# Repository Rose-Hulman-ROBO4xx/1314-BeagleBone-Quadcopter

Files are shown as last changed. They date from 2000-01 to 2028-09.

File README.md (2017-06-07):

Snoopy Copter
==========================
The quadcopter project got a rename recently. Named for the popular Peanuts character Snoopy, who always dreamed of flight, our flying Beaglebone will hopefully aid Snoopy in his quest to defeat the Red Baron!

Create an inexpensive open-source project for a BeagleBone cape quadcopter. As of the beginning of April, 2014, we have flight! Some videos of the initial flight testing are located [here](https://www.dropbox.com/sh/0pfk43b3zq14rjh/xk6Kl6lccb#/). Since then, the quadcopter has gotten easier to fly and more stable.

## Pictures ##
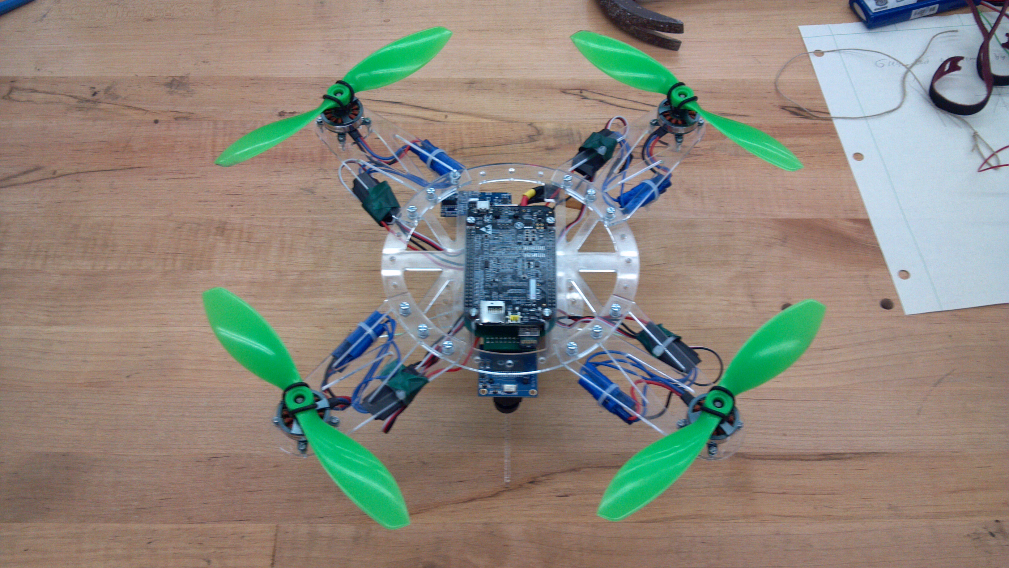
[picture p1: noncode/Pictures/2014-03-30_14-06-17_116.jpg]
View 1


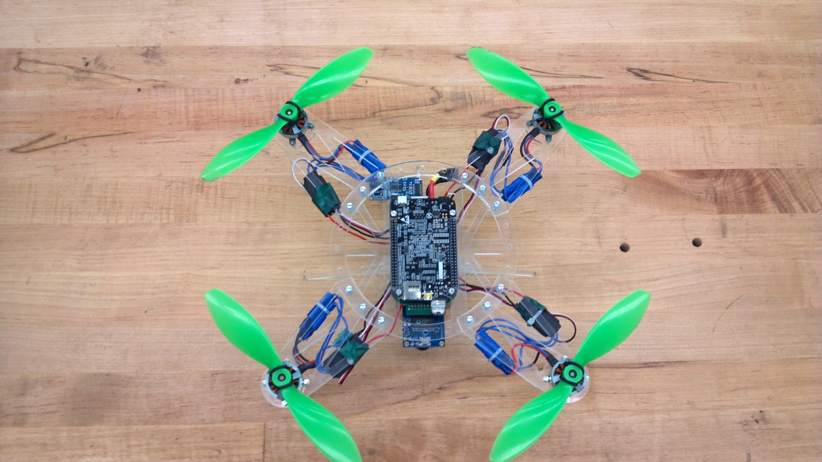
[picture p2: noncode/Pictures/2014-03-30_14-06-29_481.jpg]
View 2


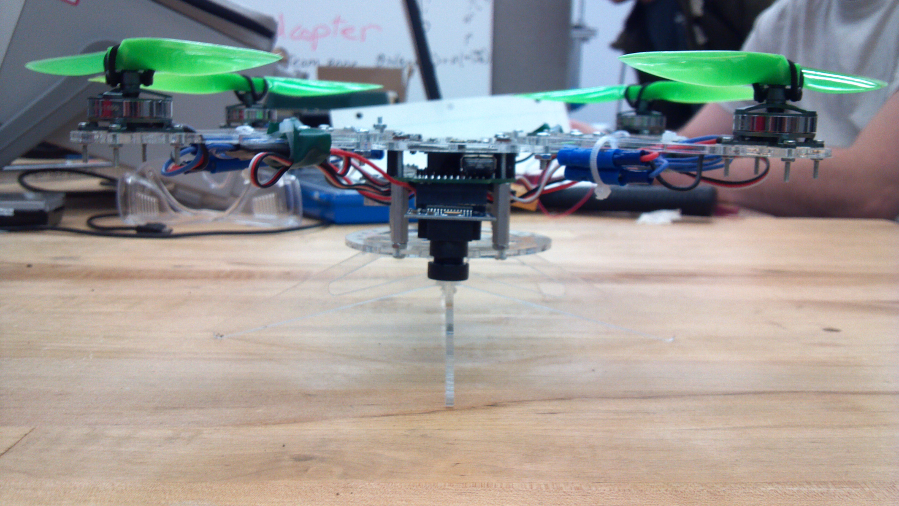
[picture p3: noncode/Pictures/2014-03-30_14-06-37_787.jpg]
View 3


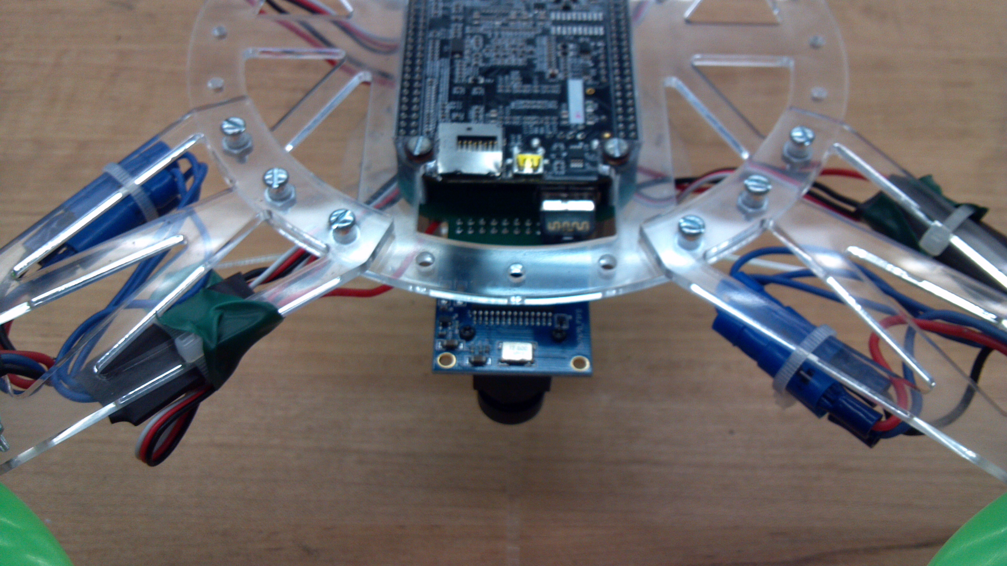
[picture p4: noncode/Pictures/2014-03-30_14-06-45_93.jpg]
View 4


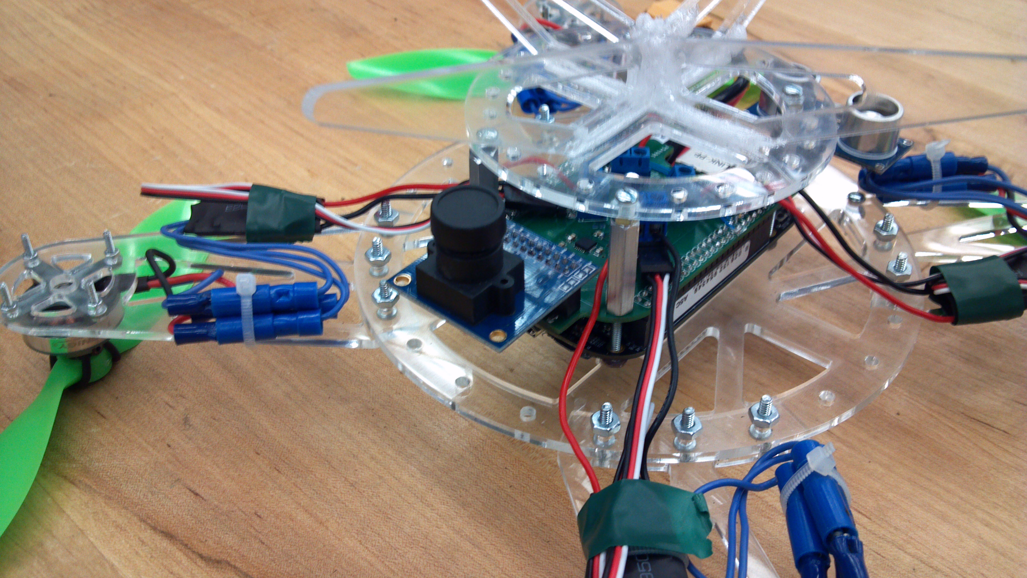
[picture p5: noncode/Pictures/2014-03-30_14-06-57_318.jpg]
View 5


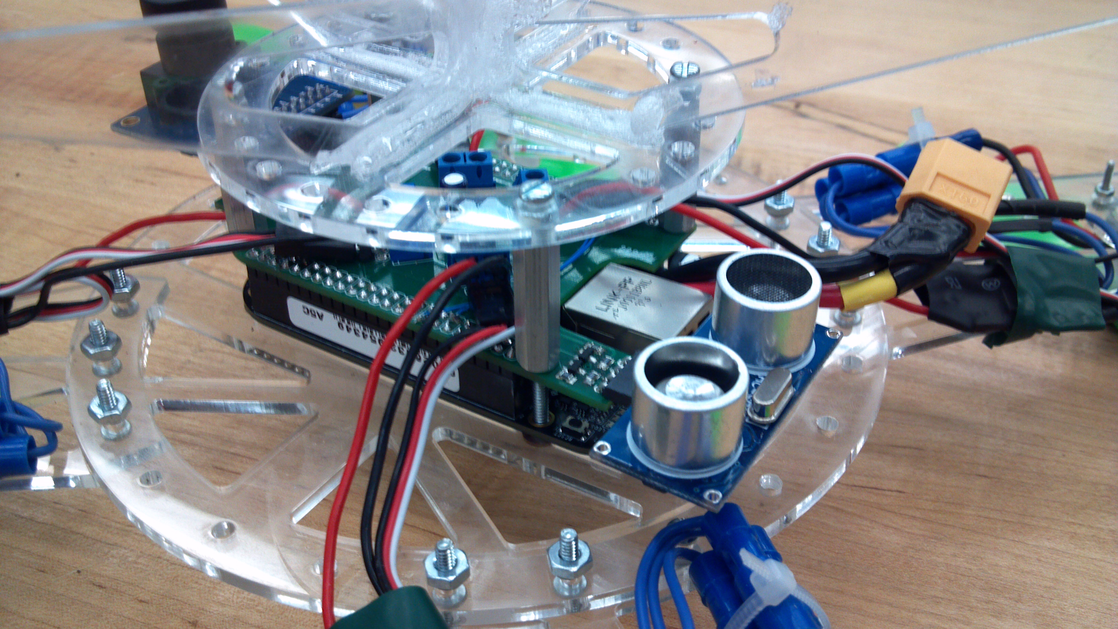
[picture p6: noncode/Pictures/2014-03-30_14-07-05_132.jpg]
View 6


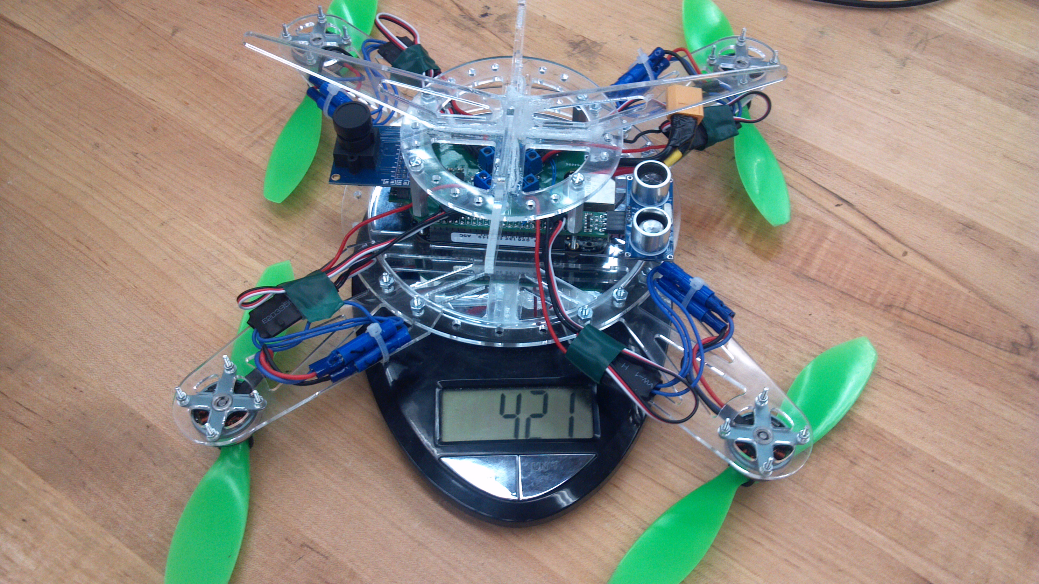
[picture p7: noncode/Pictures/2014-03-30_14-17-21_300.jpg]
View 7


421 grams!

## License ##
All software and hardware designs (frame, circuit board, etc.) here are under Creative Commons Non-Commercial Share-Alike V3.0 License, located [here](http://creativecommons.org/licenses/by-nc-sa/3.0/us/legalcode).

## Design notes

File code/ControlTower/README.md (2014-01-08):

Quadcopter Server README
========================

Necessary Hardware
------------------
1. BeagleBone Black running the latest image (9/4/2013 or later)
2. MPU 6050 six axis accelerometer and gyro
3. UWN 100 or UWN 200 USB WiFi Dongle
4. Wireless access point

Additional components such as wires and a power source may be helpful.

Necessary Software
------------------
1. Node.js
2. Various node packaged modules (I2C and MPU6050)
3. JQuery and flot
4. Source code files

All files except the installation of Node are available on this repo.

Installation
------------
1. Install Node.js
2. Install NPM
3. Install I2C and MPU6050 from NPM
4. Download all source to the correct directory

Useage
------
1. Connect the BBB to your wireless access point
2. Connect the host to the same network
3. Navigate to the proper IP address of the BBB, port 1337
4. Enjoy watching your data in real time

### Credits ###
Mike McDonald and Matt Skorina
Rose-Hulman ECE 497 Fall 2013
More detailed instructions for this project are available on the eLinux.org Wiki, located [here](http://elinux.org/ECE497_Project_Quadcopter_Server).

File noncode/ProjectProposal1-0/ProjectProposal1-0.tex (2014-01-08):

\documentclass[a4paper,10pt]{scrartcl}
\usepackage[utf8]{inputenc}
\usepackage{graphicx}

%opening
\title{Quadcopter Project Proposal}
\subtitle{ROBO 410 Dr. Mark Yoder}
\author{Team Bone and Team Sky: \\
	{\normalsize Bryce Filho (filhobc@rose-hulman.edu) }\\
	{\normalsize Chris Hopwood (hopwoocp@rose-hulman.edu) }\\
	{\normalsize Michael McDonald (mcdonamp@rose-hulman.edu) }\\
	{\normalsize Shawn Mitchell (mitchesm@rose-hulman.edu) }\\
	{\normalsize Daniel Nam (namdw@rose-hulman.edu) }\\
	{\normalsize Ryan Oliver (oliverr@rose-hulman.edu) }\\
	{\normalsize Justin Stone (stonejp@rose-hulman.edu) }\\
	{\normalsize Elias White (whiteer@rose-hulman.edu) }\\
	}

\begin{document}

\maketitle

\newpage

\tableofcontents

\begin{table}[b]
\centering
\begin{tabular}{| l | l | p{7.5cm} |}
\hline
\textbf{Revision} & \textbf{Date} & \textbf{Comments}\\
\hline
1.0 & 9/25/2013 & Initial Copy \\
\hline
\end{tabular}
\end{table}

\newpage

\section{Executive Summary}
\noindent The goal of this project is to create a plug-and-play quadcopter
add-on, or cape, solution for the BeagleBone Black.  With the recent explosion
of quadcopters among hobbyists and researchers, a platform that is affordable,
powerful without being overwhelming, and expandable fills a unique niche in the
current market. With the release of TI's BeagleBone Black, a very capable yet
affordable embedded processor, all three of these goals are attainable. The
successful completion of this project would result in a mechanical design for
the quadcopter frame, a BeagleBone Cape that houses sensors and motor
controllers, integrated flight control software for in-flight stabilization, and
the ability to communicate with a control base. We will be leveraging both our
resources at TI as well as the open source community throughout the course of
our project, and plan on open sourcing the mechanical designs, PCB schematic and
layout files, and source code.

\newpage
\section{Walkthrough}
\noindent The client contact at TI (currently Jason Kridner, the main software
developer on the Beagle Board/Bone platform) wants a quadcopter expansion
board/cape for the BeagleBone Black that is out of the box ready to fly or
almost ready to fly quadcopter, yet can still be expanded upon by the
hobbyist community and the users themselves. \\

\noindent The QuadCape and BeagleBone Black can be ordered on the client’s
website or through selected third party distributors. Upon delivery, the
customer will open the packaging and assemble the kit by attaching the
BeagleBone Black to the QuadCape, and attaching motors, propellers, and a
battery (all of which are either shipped with the kit or provided by the
user). \\

\noindent After enabling flight mode by pressing the on switch on the cape, an
LED will light indicating that the quadcopter has power and it's sensors have
been initialized. The quadcopter will then begin to fly; stably and slowly
raising altitude relative to its initial altitude. The user will then be able to
control the quadcopter via wireless communication: either a laptop or a mobile
device (phone or tablet). \\

\noindent To add functionality to the quadcopter, the customer can add software
through the continually evolving open source community that already exists
around the BeagleBone. The customer can also add hardware to the quadcopter
through any of the multiple ports of the BeagleBone Black by adding capes or
modifying the QuadCape board and building one themselves. If the user happens to
break anything, parts for the QuadCape or the quadcopter frame will be available
for purchase, and the design files will be published so users could build their
own replacements. Through this open source community the quadcopter will have
greater opportunity to be any type of project the client chooses, and will boost
the reputation of TI and the BeagleBone.

\newpage
\section{Domain Model}
\begin{figure}[h]
 \centering
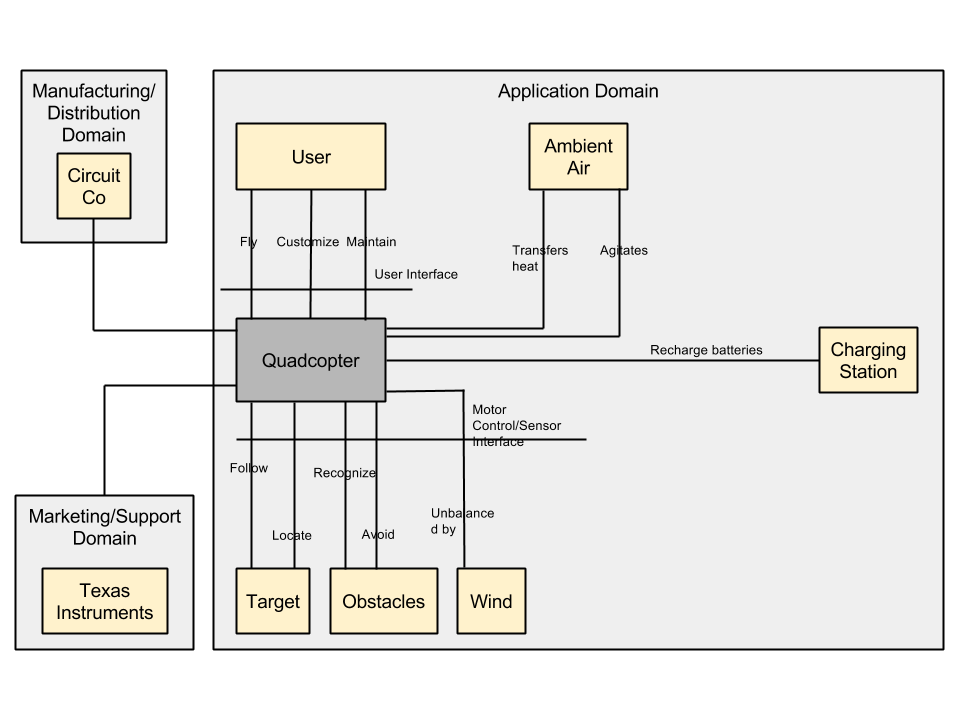
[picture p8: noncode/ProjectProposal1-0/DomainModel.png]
 
 % Domain Model.png: 960x720 pixel, 72dpi, 33.87x25.40 cm, bb=0 0 960 720
 \caption{Domain Model}
\end{figure}

\newpage
\section{Stakeholder Model}
\begin{center}
\begin{tabular}{| l | p{7.5cm} |}
\hline
\textbf{Stakeholder} & \textbf{Features}\\
\hline
Dr. Mark Yoder and Rose-Hulman & \emph{Documentation}: should be reproducible,
allow for easy future use and modification\newline
\emph{Manufacturing Cost and Time}: should be a completed product within spec
and budget, maintain/improve relationship with Texas Instruments\newline
\emph{Safety}: should be safe to build/test, as well as operate in the
future\newline
\emph{Operation Costs}: should not require special equipment or additional
overhead to use in the future\\
\hline
Jason Kridner and Texas Instruments & \emph{Customization}: should allow for
user customization, act as a marketing tool to sell additional TI products
\emph{Documentation}: should be reproducible, portable to other TI
controllers/launchpads\newline
\emph{Manufacturing Cost and Time}: should be cheap and quick to manufacture in
order to sell at a reasonable price and be more appealing than building a
quadcopter from scratch\\
\hline
CircuitCo & \emph{Customization}: should allow for expansion, without
interfering with original design and manufacturing process, may provide other
manufacturing/sales opportunities\newline
\emph{Durability}: should be well-designed and not require replacements under
warranty for normal usage\newline
\emph{Manufacturing Cost and Time}: should be efficient to manufacture, minimal
waste\newline
\emph{Maintenance}: should not require extensive hardware support\newline
\emph{Packaging}: should fit into a standard package and minimize inventory
space, be easy to ship individually and in bulk\newline
\emph{Regulatory Compliance}: should be designed to meet regulations and not
interfere with or delay the manufacturing process\\
\hline
\end{tabular}
\end{center}

\newpage
\begin{center}
\begin{tabular}{| l | p{7.5cm} |}
\hline
Hobbyist Community & \emph{Customization}: should act as a platform for design
and experimentation, should be easy to incorporate other projects, remain
open source\newline
\emph{Durability}: should be able to withstand testing and experimentation,
avoid severely damaging components\newline
\emph{Maintenance}: should be supported into its life cycle, offer replacement
parts or firmware updates\newline
\emph{Safety}: should not be a hazard to the operator or bystanders, or be
unnecessarily dangerous to modify\newline
\emph{Reliability}: both hardware and software should be robust, as countless
hours and funds may be invested into projects revolving around the
product\newline
\emph{Ease of Use}: should be easy to operate and interface with, more appealing
than building a quadcopter from scratch\newline
\emph{Operation Costs}: should not require special equipment or additional
overhead to use in the future\\
\hline
Educational Community & \emph{Customization}: should act as a platform for
design and experimentation, should be easy to incorporate other projects, remain
open source\newline
\emph{Durability}: should be able to withstand testing and experimentation,
avoid severely damaging components, resistant to student misuse
\emph{Maintenance}: should be supported into its life cycle, offer replacement
parts or firmware updates, should require minimal technical knowledge to keep
product operational\newline
\emph{Safety}: should not be a hazard to the operator or bystanders, or be
unnecessarily dangerous to modify, should be safe to use around
children/students\newline
\emph{Reliability}: both hardware and software should be robust, as countless
hours and funds may be invested into projects revolving around the
product\newline
\emph{Ease of Use}: should be easy to operate and interface with, more appealing
than building a quadcopter from scratch, should require minimal technical
knowledge to operate the completed product\newline
\emph{Operation Costs}: should not require special equipment or additional
overhead to use in the future\\
\hline
Regional Community & \emph{Environment Friendly}: should not harm the
environment through operation, provide options for disposal or recycling\newline
\emph{Safety}: should be safe to operate within a community, on a larger scale\\
\hline
\end{tabular}
\end{center}

\newpage
\section{State Model}
\begin{figure}[h]
 \centering
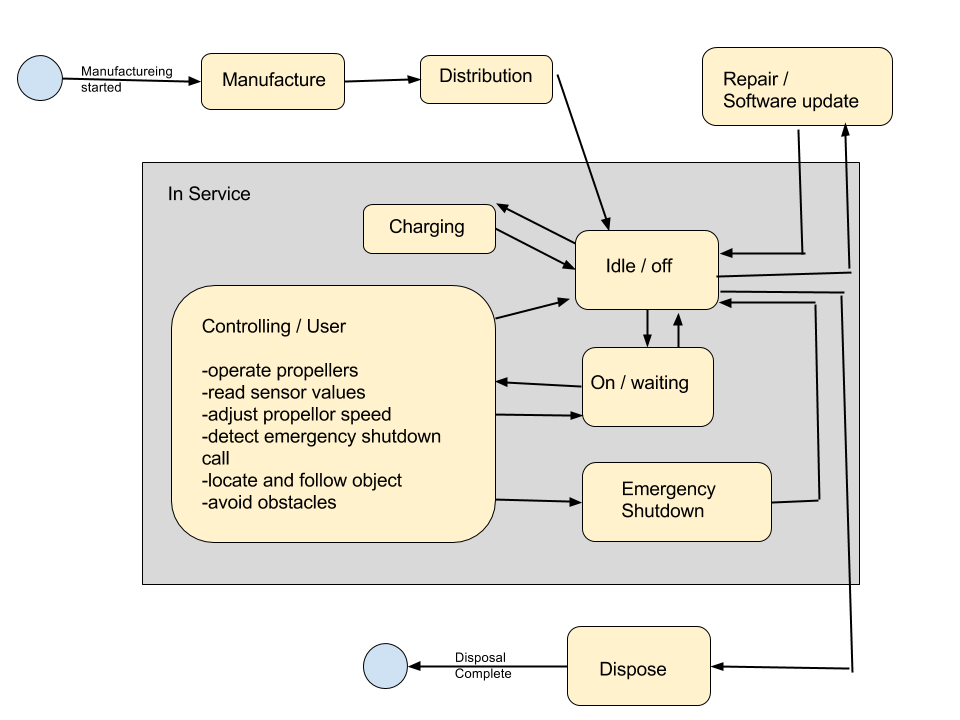
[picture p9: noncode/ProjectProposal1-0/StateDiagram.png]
 
 % State Diagram.png: 960x720 pixel, 72dpi, 33.87x25.40 cm, bb=0 0 960 720
 \caption{State Diagram}
\end{figure}

\newpage
\section{Logical Architecture}
\begin{figure}[h]
 \centering
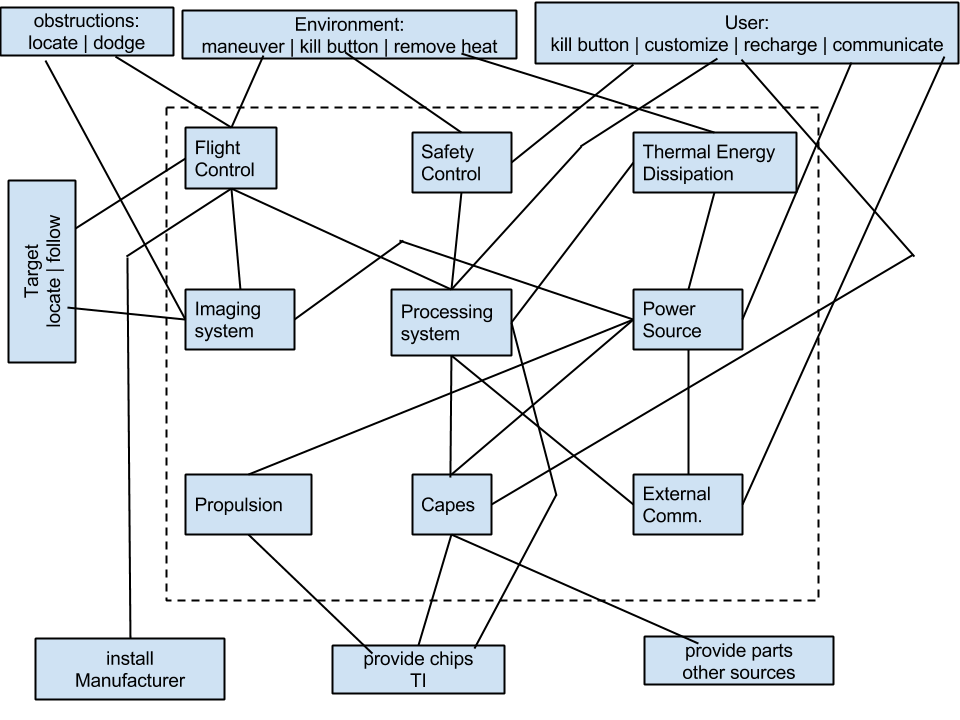
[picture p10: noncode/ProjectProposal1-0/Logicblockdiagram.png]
 
 % Logic block diagram.png: 960x720 pixel, 72dpi, 33.87x25.40 cm, bb=0 0 960 720
 \caption{Logical Architecture}
\end{figure}

\end{document}

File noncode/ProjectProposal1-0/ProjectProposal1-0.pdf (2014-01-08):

# Quadcopter Project Proposal

ROBO 410 Dr. Mark Yoder

## Team Bone and Team Sky:

Bryce Filho (filhobc@rose-hulman.edu)

Chris Hopwood (hopwoocp@rose-hulman.edu)

Michael McDonald (mcdonamp@rose-hulman.edu)

Shawn Mitchell (mitchesm@rose-hulman.edu)

Daniel Nam (namdw@rose-hulman.edu)

Ryan Oliver (oliverr@rose-hulman.edu)

Justin Stone (stonejp@rose-hulman.edu)

Elias White (whiteer@rose-hulman.edu)

## September 24, 2013

1

## Contents

1 Executive Summary | 3
2 Walkthrough | 4
3 Domain Model | 5
4 Stakeholder Model | 6
5 State Model | 9
6 Logical Architecture | 10
Revision | Date | Comments
1.0 | 9/25/2013 | Initial Copy

2

## 1 Executive Summary

The goal of this project is to create a plug-and-play quadcopter add-on, or cape, solution for the BeagleBone Black. With the recent explosion of quadcopters among hobbyists and researchers, a platform that is affordable, powerful without being overwhelming, and expandable fills a unique niche in the current market. With the release of TI’s BeagleBone Black, a very capable yet affordable embedded processor, all three of these goals are attainable. The successful completion of this project would result in a mechanical design for the quadcopter frame, a BeagleBone Cape that houses sensors and motor controllers, integrated flight control software for in-flight stabilization, and the ability to communicate with a control base. We will be leveraging both our resources at TI as well as the open source community throughout the course of our project, and plan on open sourcing the mechanical designs, PCB schematic and layout files, and source code.

3

## 2 Walkthrough

The client contact at TI (currently Jason Kridner, the main software developer on the Beagle Board/Bone platform) wants a quadcopter expansion board/cape for the BeagleBone Black that is out of the box ready to fly or almost ready to fly quadcopter, yet can still be expanded upon by the hobbyist community and the users themselves.

The QuadCape and BeagleBone Black can be ordered on the client’s website or through selected third party distributors. Upon delivery, the customer will open the packaging and assemble the kit by attaching the BeagleBone Black to the QuadCape, and attaching motors, propellers, and a battery (all of which are either shipped with the kit or provided by the user).

After enabling flight mode by pressing the on switch on the cape, an LED will light indicating that the quadcopter has power and it’s sensors have been initialized. The quadcopter will then begin to fly; stably and slowly raising altitude relative to its initial altitude. The user will then be able to control the quadcopter via wireless communication: either a laptop or a mobile device (phone or tablet).

To add functionality to the quadcopter, the customer can add software through the continually evolving open source community that already exists around the Beagle-Bone. The customer can also add hardware to the quadcopter through any of the multiple ports of the BeagleBone Black by adding capes or modifying the QuadCape board and building one themselves. If the user happens to break anything, parts for the QuadCape or the quadcopter frame will be available for purchase, and the design files will be published so users could build their own replacements. Through this open source community the quadcopter will have greater opportunity to be any type of project the client chooses, and will boost the reputation of TI and the BeagleBone.

4

## 3 Domain Model

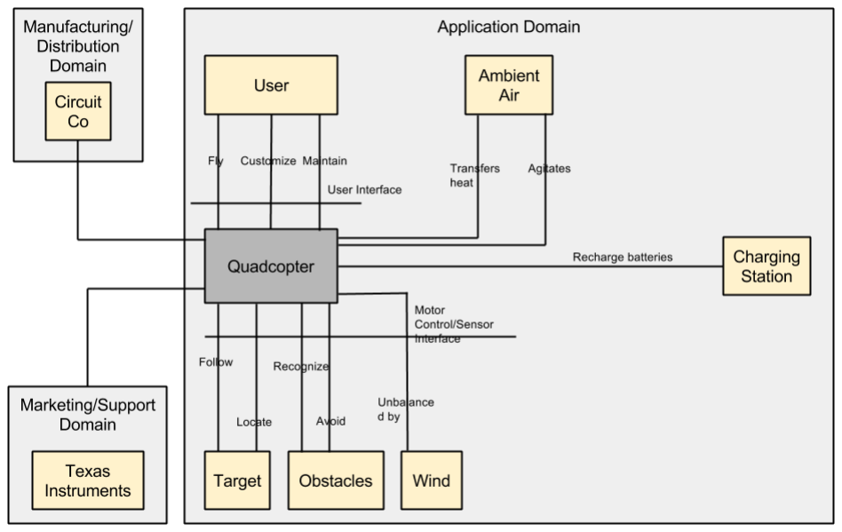
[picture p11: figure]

Figure 1: Domain Model

5

## 4 Stakeholder Model

Stakeholder | Features
Dr. Mark Yoder and Rose-Hulman | Documentation: should be reproducible, allow for easy future use and modification Manufacturing Cost and Time: should be a com-pleted product within spec and budget, main-tain/improve relationship with Texas Instru-ments Safety: should be safe to build/test, as well as operate in the future Operation Costs: should not require special equipment or additional overhead to use in the future
Jason Kridner and Texas Instruments | Customization: should allow for user customiza-tion, act as a marketing tool to sell ad-ditional TI products Documentation: should be reproducible, portable to other TI con-trollers/launchpads Manufacturing Cost and Time: should be cheap and quick to manufacture in order to sell at a rea-sonable price and be more appealing than build-ing a quadcopter from scratch
CircuitCo | Customization: should allow for expansion, with- out interfering with original design and manufac- turing process, may provide other manufactur- ing/sales opportunities Durability: should be well-designed and not re- quire replacements under warranty for normal us- age Manufacturing Cost and Time: should be effi- cient to manufacture, minimal waste Maintenance: should not require extensive hard- ware support Packaging: should fit into a standard package and minimize inventory space, be easy to ship individ- ually and in bulk Regulatory Compliance: should be designed to meet regulations and not interfere with or delay the manufacturing process

6

Hobbyist Community Customization: should act as a platform for design and experimentation, should be easy to incorporate other projects, remain open source Durability: should be able to withstand testing and experimentation, avoid severely damaging components
Maintenance: should be supported into its life cycle, offer replacement parts or firmware updates Safety: should not be a hazard to the operator or bystanders, or be unnecessarily dangerous to modify
Reliability: both hardware and software should be robust, as countless hours and funds may be invested into projects revolving around the product
Ease of Use: should be easy to operate and interface with, more appealing than building a quadcopter from scratch
Operation Costs: should not require special equipment or additional overhead to use in the future
Educational Community Customization: should act as a platform for design and experimentation, should be easy to incorporate other projects, remain open source Durability: should be able to withstand testing and experimentation, avoid severely damaging components, resistant to student misuse Maintenance: should be supported into its life cycle, offer replacement parts or firmware updates, should require minimal technical knowledge to keep product operational
Safety: should not be a hazard to the operator or bystanders, or be unnecessarily dangerous to modify, should be safe to use around children/students
Reliability: both hardware and software should be robust, as countless hours and funds may be invested into projects revolving around the product
Ease of Use: should be easy to operate and interface with, more appealing than building a quadcopter from scratch, should require minimal technical knowledge to operate the completed product Operation Costs: should not require special equipment or additional overhead to use in the future
Regional Community Environment Friendly: should not harm the environment through operation, provide options for disposal or recycling
Safety: should be safe to operate within a community, on a larger scale

7

## 5 State Model

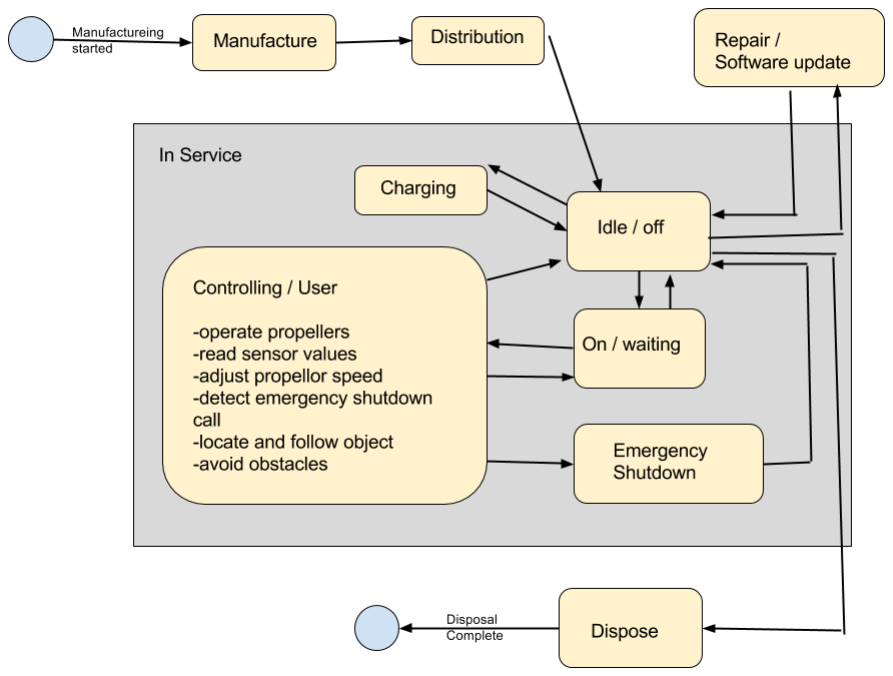
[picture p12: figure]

Figure 2: State Diagram

8

## 6 Logical Architecture

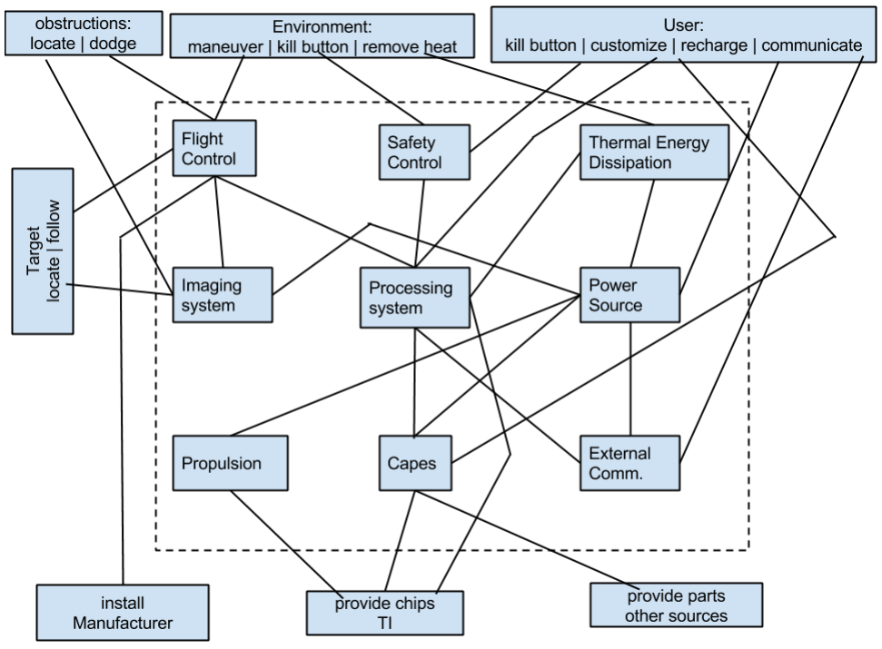
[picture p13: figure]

Figure 3: Logical Architecture

9

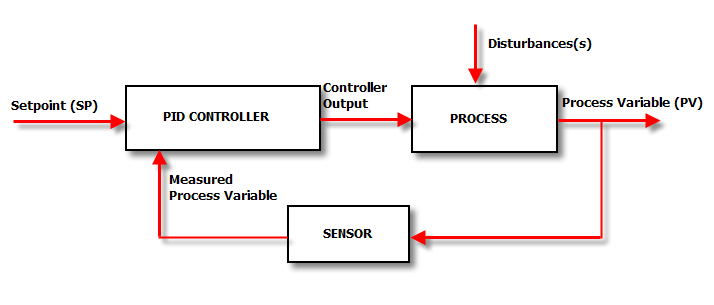
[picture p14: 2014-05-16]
noncode/Pictures/PWM Process Overview.png

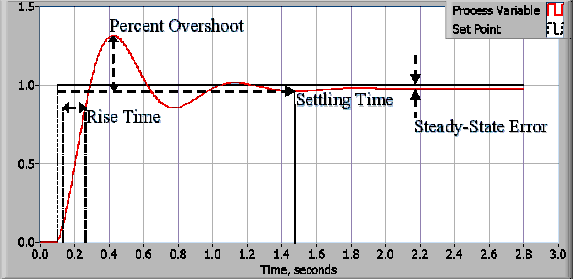
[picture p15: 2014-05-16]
noncode/Pictures/Example Output.png

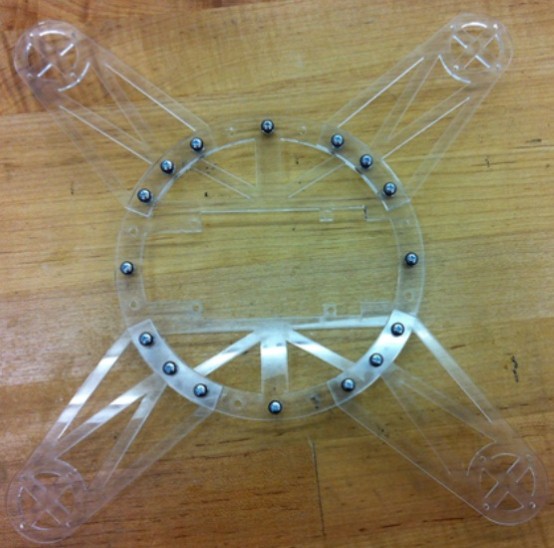
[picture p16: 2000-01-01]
code/ControlTower/images/Frame.jpg

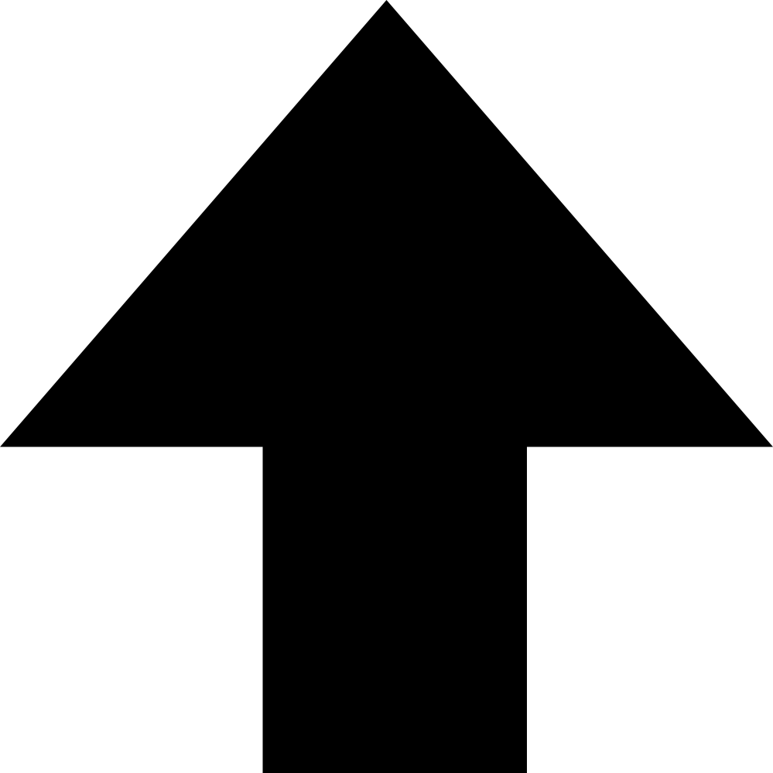
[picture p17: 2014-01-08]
code/ControlTower/Images/up_arrow-999px.png

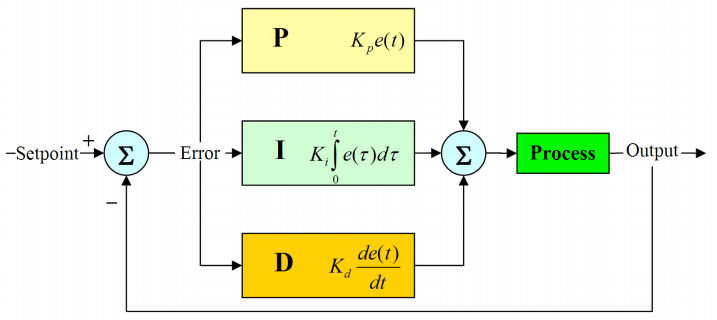
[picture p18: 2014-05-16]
noncode/Pictures/PID Control.png

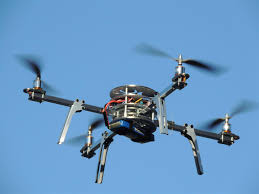
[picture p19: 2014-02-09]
code/ControlTower/images/quadcopter.jpg

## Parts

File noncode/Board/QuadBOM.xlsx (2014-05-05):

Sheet: Board
Qty | Value | Device | Package | Parts | Description | MF | MPN | Purchase Link | Individual | 1k Volume Cost | Line Total (Individual) | Line Total (Volume)
4 | 0.1uF 6.3V | C-USC0805 | C0805 | C1, C2, C6, C7 | CAPACITOR, American symbol | Kemet | C0805C104K9RACTU | http://www.digikey.com/product-detail/en/C0805C104K9RACTU/399-9155-1-ND/3522673 | 0.12 | 0.02228 | 0.48 | 0.08912
1 | 2.2nF 50V | C-USC0805 | C0805 | C3 | CAPACITOR, American symbol | Kemet | C0805C222K5RACTU | http://www.digikey.com/product-detail/en/C0805C222K5RACTU/399-1151-1-ND/411426 | 0.1 | 0.0102 | 0.1 | 0.0102
3 | 10nF 16V | C-USC0805 | C0805 | C4, C9, C11 | CAPACITOR, American symbol | Kemet | C0805C103K4RACTU | http://www.digikey.com/product-detail/en/C0805C103K4RACTU/399-7995-1-ND/3471718 | 0.24 | 0.05875 | 0.72 | 0.17625
1 | 10uF 25V |  | CPOL-RADIAL-10UF-25V | C5 | CAP-08440 | CDE | SK100M025ST | http://www.digikey.com/product-detail/en/SK100M025ST/338-1697-ND/1627382 | 0.21 | 0.078 | 0.21 | 0.078
2 | 1uF 16V | C-USC0805 | C0805 | C8, C10 | CAPACITOR, American symbol | Kemet | C0805C105K4RACTU | http://www.digikey.com/product-detail/en/C0805C105K4RACTU/399-1284-1-ND/416060 | 0.12 | 0.222 | 0.24 | 0.444
1 | M02PTH | M02PTH | 1X02 | JP1 | Standard 2-pin 0.1 header | Samtec | TSW-102-25-G-S-RA |  | 0.02906666667 | 0.01453506667 | 0.02906666667 | 0.01453506667
1 | M04PTH | M02PTH RA | 1x04 | JP10 | Standard 4-pin 0.1 header | Samtec | SSQ-104-02-G-S-RA |  | 1.11 | 0.55418 | 1.11 | 0.55418
1 | M211PTH | M211PTH | 2x11 | JP11 | Standard 2x11-pin 0.1 header | Samtec | SSQ-111-21-G-D |  | 2.58 | 1.2896 | 2.58 | 1.2896
4 | M03PTH | M03PTH RA | 1X03 | JP2, JP3, JP4, JP5 | Standard 3-pin 0.1 header | Samtec | TSW-103-25-G-S-RA |  | 0.0436 | 0.0218026 | 0.1744 | 0.0872104
4 | M025MM | M025MM | SCREWTERMINAL-5MM-2 | JP6, JP7, JP8, JP9 | 2-pin 5mm screw terminal | OST | OSTTC020162 | http://www.digikey.com/product-detail/en/OSTTC020162/ED2600-ND/614549 | 0.41 | 0.1925 | 1.64 | 0.77
1 | FB | INDUCTOR0805 | L0805 | L1 | Inductors | Laird | HZ0805E601R-10 | http://www.digikey.com/product-detail/en/HZ0805E601R-10/240-2399-1-ND/806759 | 0.1 | 0.02195 | 0.1 | 0.02195
1 | GREEN | LEDCHIP-LED0805 | CHIP-LED0805 | LED1 | LED GREEN | OSRAM Opto Semi | LG R971-KN-1 | http://www.digikey.com/product-detail/en/LG%20R971-KN-1/475-1410-1-ND/1802598 | 0.08 | 0.0437 | 0.08 | 0.0437
2 |  | BSS 138 | SOT23 | Q1, Q2 | N-Channel Mosfet | Fairchild | BSS 138 | http://www.digikey.com/product-detail/en/BSS138/BSS138CT-ND/244294 | 0.22 | 0.03998 | 0.44 | 0.07996
6 | 0 | R-US_M0805 | M0805 | R1, R5, R9, R10, R11, R12 | RESISTOR, American symbol | Stackpole | RMCF0805ZT0R00 | http://www.digikey.com/product-detail/en/RMCF0805ZT0R00/RMCF0805ZT0R00CT-ND/1942606 | 0.03 | 0.0032 | 0.18 | 0.0192
1 | 150 | R-US_M0805 | M0805 | R17 | RESISTOR, American symbol | Stackpole | RMCF0805JT150R | http://www.digikey.com/product-detail/en/RMCF0805JT150R/RMCF0805JT150RCT-ND/1942541 | 0.03 | 0.0032 | 0.03 | 0.0032
8 | 10000 | R-US_M0805 | M0805 | R2, R3, R4, R6, R13, R14, R15, R16 | RESISTOR, American symbol | Stackpole | RMCF0805FT10K0 | http://www.digikey.com/product-detail/en/RMCF0805FT10K0/RMCF0805FT10K0CT-ND/1942435 | 0.04 | 0.00448 | 0.32 | 0.03584
2 | 1000 | R-US_M0805 | M0805 | R7, R8 | RESISTOR, American symbol | Stackpole | RMCF0805JT1K00 | http://www.digikey.com/product-detail/en/RMCF0805JT1K00/RMCF0805JT1K00CT-ND/1942557 | 0.03 | 0.0032 | 0.06 | 0.0064
1 | BMP180 | BMP180 | BMP180 | U1 | BOSCH BMP180 DIGITAL BAROMETRIC PRESSURE SENSOR | Bosch Sensortec | BMP 180 | http://www.mouser.com/ProductDetail/Bosch-Sensortec/BMP180/?qs=sGAEpiMZZMsrChSOYEGTCcbpL13VfRyojs5HQb1tBiU%3d | 3.71 | 2.24 | 3.71 | 2.24
1 | MPU9150 | MPU-9150QFN-24-NP | QFN-24-NP | U2 | 9DOF (3mag, 3accel, 3rotat). I2C interface. | Invensense | MPU 9150 | http://www.digikey.com/product-detail/en/MPU-9150/1428-1009-1-ND/4038014 | 14.53 | 8.3 | 14.53 | 8.3
1 | GPS | GPS_FGPMMOPA6H | FGPMMOPA6H | U3 | GPS Module - MTK MT3339 Chipset, -165dBm sensitivity, 22 channels, 10Hz, auto-select external antenna options | GlobalTop Technology | FGPMMOPA6H | http://www.adafruit.com/products/790#Description | 29.95 | 15 | 29.95 | 15
1 | MAX1704X | MAX1704X | TDFN-8 | U4 | MAX17043/MAX17044: Battery Fuel Guage (43 is 1cell, 44 is 2cell) | Maxim Semiconductor | MAX 17044 |  | 2.15 | 1.22 | 2.15 | 1.22
1 | OMV-CAMERA | OMV-CAMERA | OMV-CAMERA | U5 | Omnivision Camera Module | Omnivision |  |  | 5 | 5 | 5 | 5 | ???
1 |  |  |  | Board | Printed Circuit Board |  |  |  | 33 | 1.39 | 33 | 1.39 | MFGR As Of Yet Unknown
 |  |  |  |  |  |  |  |  |  |  | 96.83346667 | 36.87334547

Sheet: Flight
Qty | Value | Device | Package | Parts | Description | MF | MF Link | MPN | Purchase Link | Individual | 1k Volume Cost | Line Total (Individual) | Line Total (Volume)
4 |  |  |  | M1, M2, M3, M4 |  | Turnigy |  | 2203/4/5C | http://www.hobbyking.com/hobbyking/store/__7520__2205C_1400Kv_Brushless_motor.html | 10.29 | 6.5 | 41.16 | 26
4 |  |  |  | ESC1, ESC2, ESC3, ESC4 |  | Hobbyking |  | 8/10A | http://www.hobbyking.com/hobbyking/store/__6455__Hobbyking_SS_Series_8_10A_ESC.html | 6.15 | 4.5 | 24.6 | 18
1 |  |  |  | BATT |  | Turnigy |  | 1800 mAh 2S | http://www.hobbyking.com/hobbyking/store/__9169__Turnigy_1800mAh_2S_20C_Lipo_Pack.html | 8.19 | 6.6 | 8.19 | 6.6
2 |  |  |  | P1, P2 | CR Prop | GWS |  |  | http://www.hobbyking.com/hobbyking/store/__27329__GWS_EP_Counter_Rotating_Propeller_RH_8060_203x152mm_Green_6pcs_set_.html | 0.6533333333 | 0.4 | 1.306666667 | 0.8 | ???
2 |  |  |  | P3, P4 | Prop | GWS |  |  | http://www.hobbyking.com/hobbyking/store/__27362__GWS_EP_Propeller_RD_8060_203x152mm_green_6pcs_set_.html | 0.6533333333 | 0.4 | 1.306666667 | 0.8 | ???
 |  |  |  |  |  |  |  |  |  |  |  | 76.56333333 | 52.2

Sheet: Hardware
Qty | Value | Device | Package | Parts | Description | MF | MF Link | MPN | Purchase Link | Individual | 1k Volume Cost | Line Total (Individual) | Line Total (Volume)

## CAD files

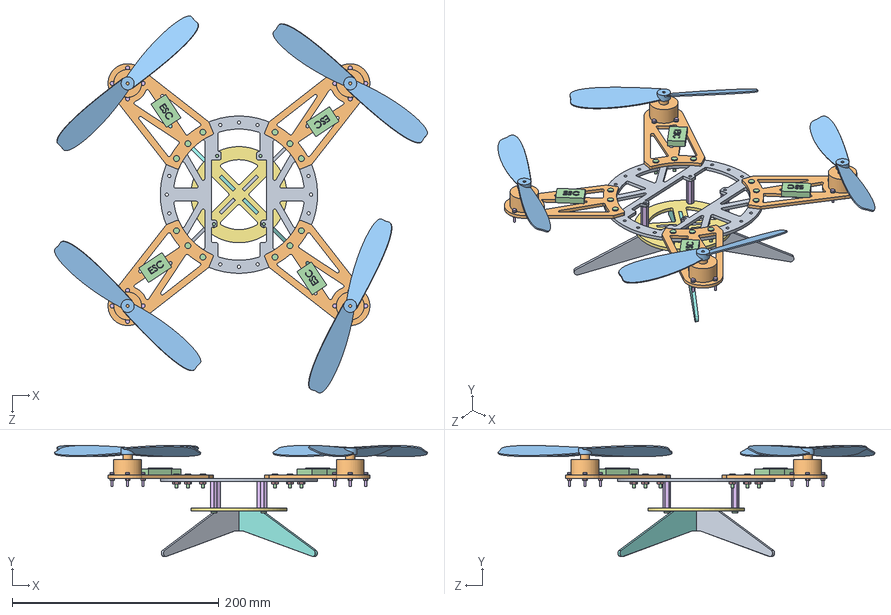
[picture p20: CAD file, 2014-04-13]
noncode/CAD/Quadcopter 4.0.SLDASM
361.2 x 107.5 x 365.1 mm
Frame 4.0
Arm 4.0 x 4
Lock Washer #4 x 16
Screw 4-40 x 0.5 x 16
Nut 4-40 x 12
Standoff 4-40 x 1 x 4
Battery Tray 4.0
Leg1 4.0
Leg2 4.0
Motor x 4
Propellor x 4
ESC x 4
Nut M2 x 16
Screw M2 x 12 x 16
Washer M2 x 16

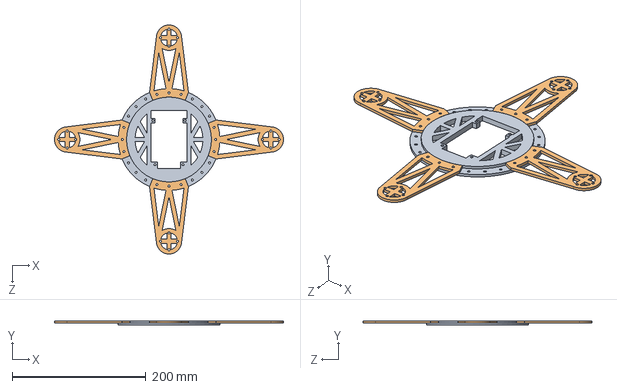
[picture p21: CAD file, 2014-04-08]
noncode/CAD/Quadcopter 1.0.SLDASM
342.9 x 6.35 x 342.9 mm
Quadcopter Frame 4
Quadcopter Arm x 4

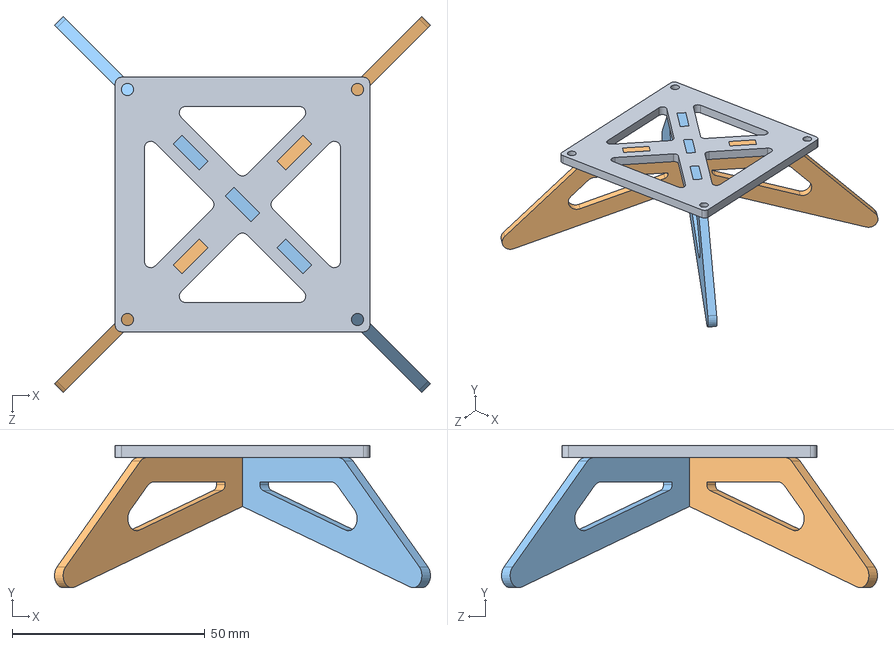
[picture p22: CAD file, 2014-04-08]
noncode/CAD/Landing Gear 1.0.SLDASM
97.6 x 37.0 x 97.6 mm
Slotted Battery Tray
Leg2
Leg1

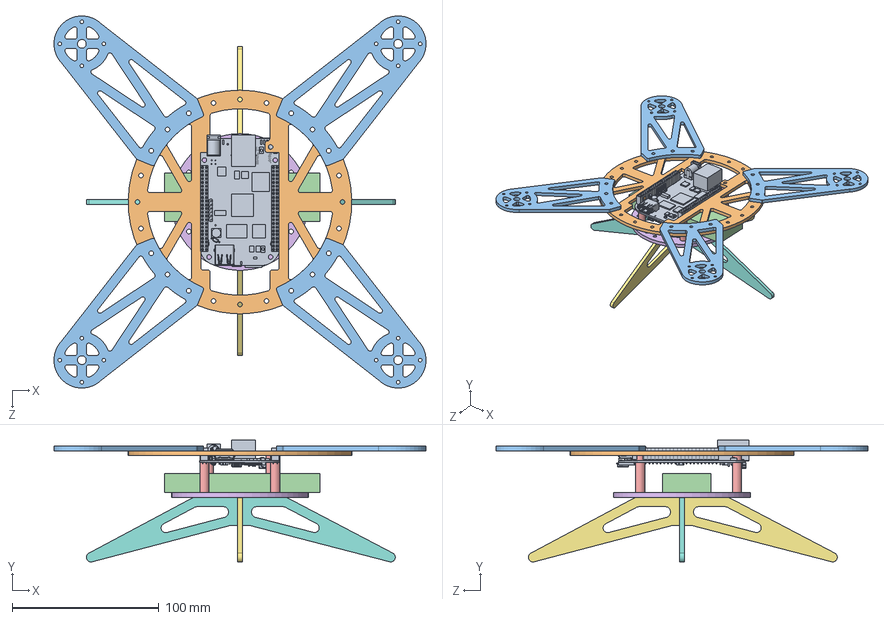
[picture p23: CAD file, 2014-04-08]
noncode/CAD/Quadcopter Landing Gear 1.0.SLDASM
253.5 x 83.1 x 253.5 mm
Quadcopter Frame Prototype
Quadcopter Arm Prototype x 4
Quadcopter Standoff x 4
Quadcopter Battery Tray_mod
Leg2_mod
Leg1_mod

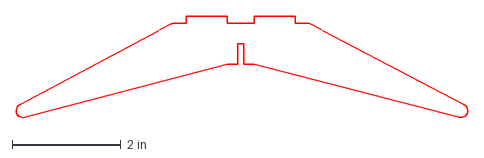
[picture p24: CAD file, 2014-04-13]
noncode/CAD/Leg1 4.0 solid plywood tabbed.dxf
8.29 x 1.87 in

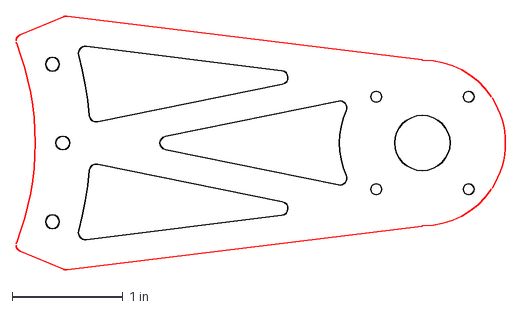
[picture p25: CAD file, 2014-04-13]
noncode/CAD/Arm 4.0 tabbed.dxf
4.46 x 2.29 in

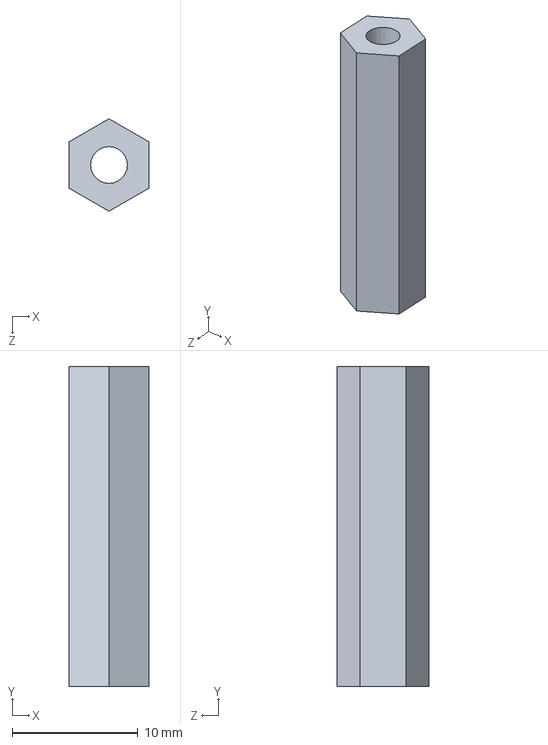
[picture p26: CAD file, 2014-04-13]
noncode/CAD/Standoff 4-40 x 1.SLDPRT
6.36 x 25.4 x 7.34 mm

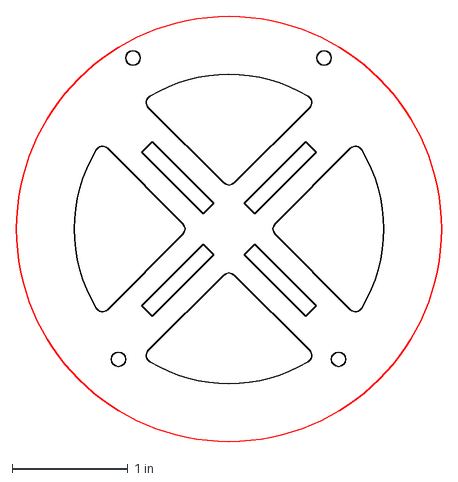
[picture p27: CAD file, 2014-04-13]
noncode/CAD/Battery Tray 4.0 ideal.dxf
3.67 x 3.67 in

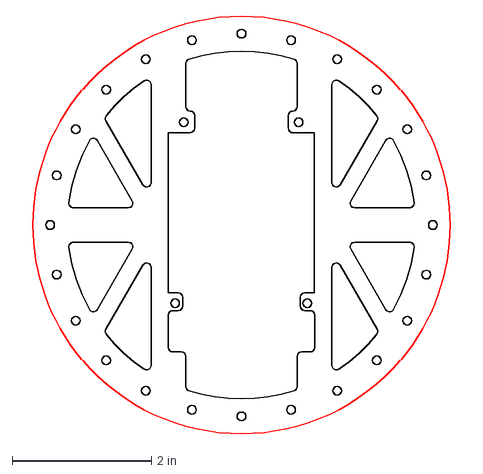
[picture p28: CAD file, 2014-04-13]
noncode/CAD/Frame 4.0 tabbed.dxf
6.47 x 6.00 in

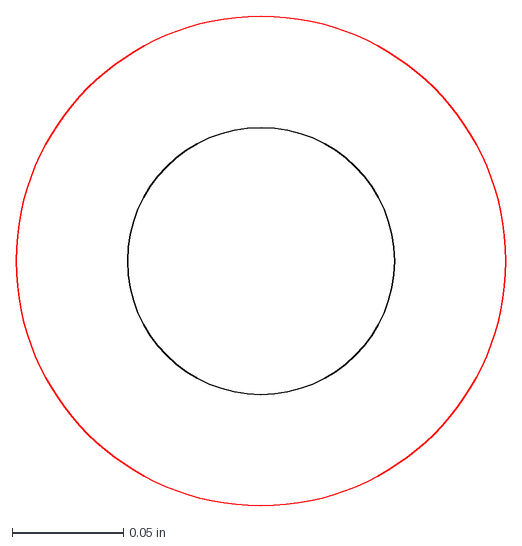
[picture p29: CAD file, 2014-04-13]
noncode/CAD/spacer.dxf
0.22 x 0.22 in

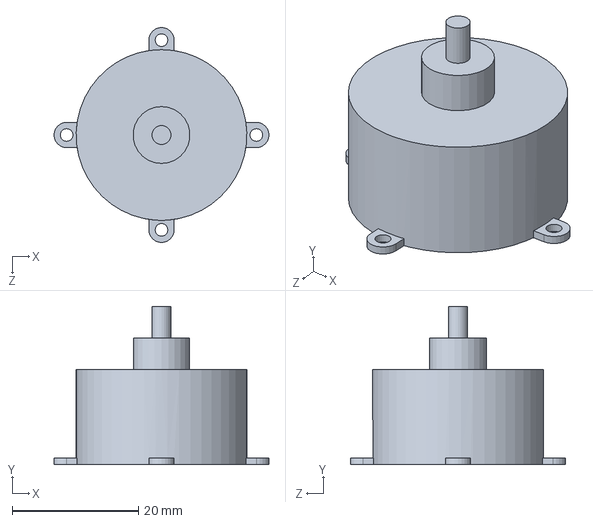
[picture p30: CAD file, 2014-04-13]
noncode/CAD/Motor.SLDPRT
34.0 x 25.0 x 34.0 mm

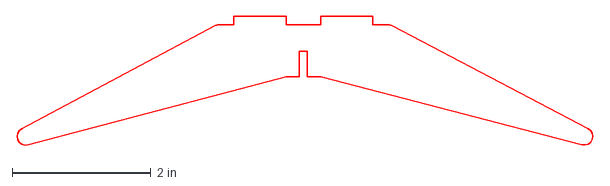
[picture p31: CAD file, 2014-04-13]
noncode/CAD/Leg1 4.0 solid ideal.dxf
8.32 x 1.87 in

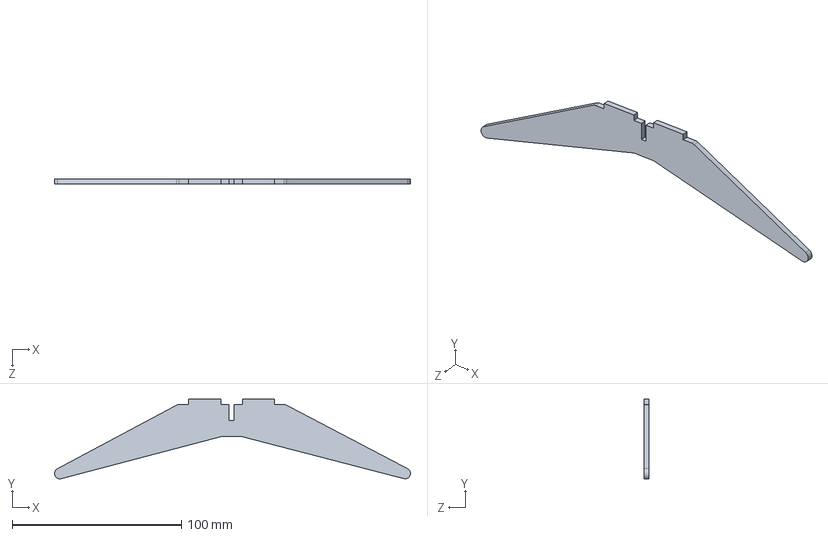
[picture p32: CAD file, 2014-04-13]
noncode/CAD/Leg2 4.0.SLDPRT
210.5 x 47.2 x 3.17 mm

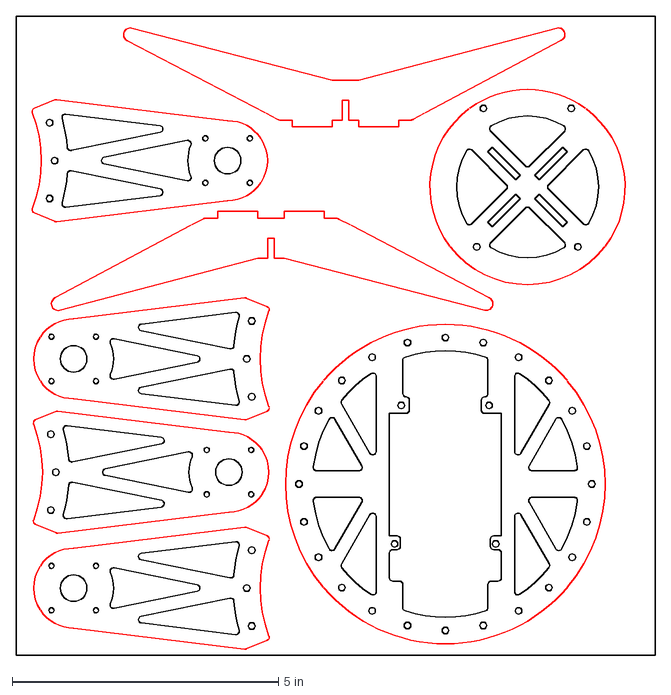
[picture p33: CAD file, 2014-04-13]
noncode/CAD/Layout 12x12 with Grain tabbed.dxf
12.0 x 12.0 in

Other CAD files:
noncode/CAD/Battery Tray 4.0 plywood tabbed.dxf
noncode/CAD/Layout 12x24 Plywood 4-7-14.dxf
noncode/CAD/Leg1 4.0.SLDPRT
noncode/CAD/ESC.SLDPRT
noncode/CAD/Arm 1.0.DXF
noncode/CAD/Arm 1.0.SLDPRT
noncode/CAD/Arm 2.0.DXF
noncode/CAD/Arm 2.0.SLDPRT
noncode/CAD/Arm 3.0.SLDPRT
noncode/CAD/Arm 3.0.dxf
noncode/CAD/Arm 4.0.SLDPRT
noncode/CAD/Arm 4.0.dxf
noncode/CAD/BEAGLEBONE_BLACK_BOARD.SLDPRT
noncode/CAD/Battery 1.0.SLDPRT
noncode/CAD/Battery Tray 1.0.DXF
noncode/CAD/Battery Tray 1.0.SLDPRT
noncode/CAD/Battery Tray 1.5.SLDPRT
noncode/CAD/Battery Tray 2.0.DXF
noncode/CAD/Battery Tray 2.0.SLDPRT
noncode/CAD/Battery Tray 3.0.SLDPRT
noncode/CAD/Battery Tray 3.0.dxf
noncode/CAD/Battery Tray 4.0 plywood.dxf
noncode/CAD/Battery Tray 4.0.SLDPRT
noncode/CAD/Battery Tray 4.0.dxf
noncode/CAD/Frame 1.0.DXF
noncode/CAD/Frame 1.0.SLDPRT
noncode/CAD/Frame 2.0.SLDPRT
noncode/CAD/Frame 2.0.dxf
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

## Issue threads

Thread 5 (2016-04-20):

build videos?

NIXOYE, 2016-04-20:
are their any plans on making videos on the process of putting one together?

rockybulwinkle, 2016-04-21:
Not really.  This was a senior design project.  As far as I am aware, everyone has moved on.  Please note that master_rev2 became our main branch.  At some point I am going to merge it into master.

rockybulwinkle, 2016-04-21:
All that said, the construction of the frame is fairly simple.  If you go to master_rev2, there are pictures.

NIXOYE, 2016-04-21:
can you link it? also, was there any work on adding gps or wifi to it so it could follow a device? so you could have it trail behind you or be able to get to a saved location?

rockybulwinkle, 2016-04-21:
We had planned on a GPS module.  IIRC, it even has a spot where you'd solder it to the PCB.  But we didn't get to it before we graduated.  In the software's current state, it only supports R/C mode.

rockybulwinkle, 2016-04-21:
By R/C mode, I mean dual analog sticks that control throttle, yaw, roll, and pitch.

rockybulwinkle, 2016-04-21:
Take a look at the master_rev2 home page:
https://github.com/Rose-Hulman-ROBO4xx/1314-BeagleBone-Quadcopter/tree/master_rev2

NIXOYE, 2016-04-21:
oh, wow did you guys not see how amazing this project is and just get the grade forget about it? was the beaglebone detachable from the copter parts easily? also is there also open guides for the control or remote or whatever you called the device to drive it?

NIXOYE, 2016-04-21:
its so beautiful.

rockybulwinkle, 2016-04-21:
No, we get how cool this was ;)

Frankly, after we graduated we didn't have much time to continue development, though some of us wanted to, myself included.  I may still pick up this project again.  It was my baby, ya know?

it wasn't too hard to separate the bone from the frame.  IIRC, you unscrewed four screws and carefully remove it from the PCB.

NIXOYE, 2016-04-21:
did you guys try carrying anything with it? i hope you do pick this up again!

rockybulwinkle, 2016-04-21:
No, we didn't try carrying anything with it.  The controls were a little unwieldily as it was.  And I say that as an R/C pilot with more than 15 years of experience.

rockybulwinkle, 2016-04-21:
Somehow we had the nerve to fly it in an auditorium full of people XD.

rockybulwinkle, 2016-04-21:
Be sure to check out the dropbox videos, if you didn't see them already.  I'm the guy with the deeper voice and beard. :p

NIXOYE, 2016-04-21:
hm, well with gps\cameras itd probably be pretty straightforward to get it to drive itself. it might even be able to use something like openCV to follow directly above you

NIXOYE, 2016-04-21:
yeah i have the dropbox bookmarked as soon as i came accros this project

rockybulwinkle, 2016-04-21:
Are you a Rose-Hulman student as well?

rockybulwinkle, 2016-04-21:
"also is there also open guides for the control or remote or whatever you called the device to drive it?"

To control it, you connect to a web server hosted on the bone (it acts as an access point).  The website uses some joystick API.  We tried using both an xbox controller and a *proper* R/C controller, specifically the DX6.

rockybulwinkle, 2016-04-21:
commands are sent to control_alg by writing to a FIFO and it constantly writes the latest image from the camera to a ramfs.  So really you could drive it with a program other than the web server if you wish.

rockybulwinkle, 2016-04-21:
If you have any other questions, just ask.

NIXOYE, 2016-04-21:
nop, i was looking around for a project i thought i had seen online and came across this.

it'd be interesting to see if you could set it up with a cameras so it could move around like teslas/geohots comma.ai project and be able to have it avoid people\buildings on its own.

NIXOYE, 2016-04-21:
how durable were they when they fell. did it actually break that time it fell and someone said it broke?

rockybulwinkle, 2016-04-21:
They were pretty fragile.  We did move to plywood/bass wood frames, which both helped the weight and improved durability.

rockybulwinkle, 2016-04-21:
Initially it was acrylic.

NIXOYE, 2016-04-21:
how many did you all build? did you ever look aronud for what GPS you could add to the soldering spot?

rockybulwinkle, 2016-04-21:
IIRC, we ordered several of our custom PCBs but only populated maybe 2 or 3.  We built many, many frames worth of parts and backups.

rockybulwinkle, 2016-04-21:
I forget what GPS we designed it for.  It was a specific model.  I don't think they all share the same footprint, ya know?

NIXOYE, 2016-04-21:
were there any notes or something kept where it might be? i wonder how small cameras can get now that could work with it without putting to much weight. maybe one on each of the things that copter line up the copter wings.

rockybulwinkle, 2016-04-21:
Yeah, I'm sure there are notes somewhere.  They might be on my google drive, i.e. not public though.  The camera was an OV7670 which I wrote a PRU program for.  It read the FIFO off the camera and stored it in memory shared with the ARM.  It worked well enough, but was a pain to get going.  It involved a lot of assembly and magic.

IIRC, we went that route with the camera because we wanted to use the single USB port for networking, and didn't want to have a USB hub strapped to the side.

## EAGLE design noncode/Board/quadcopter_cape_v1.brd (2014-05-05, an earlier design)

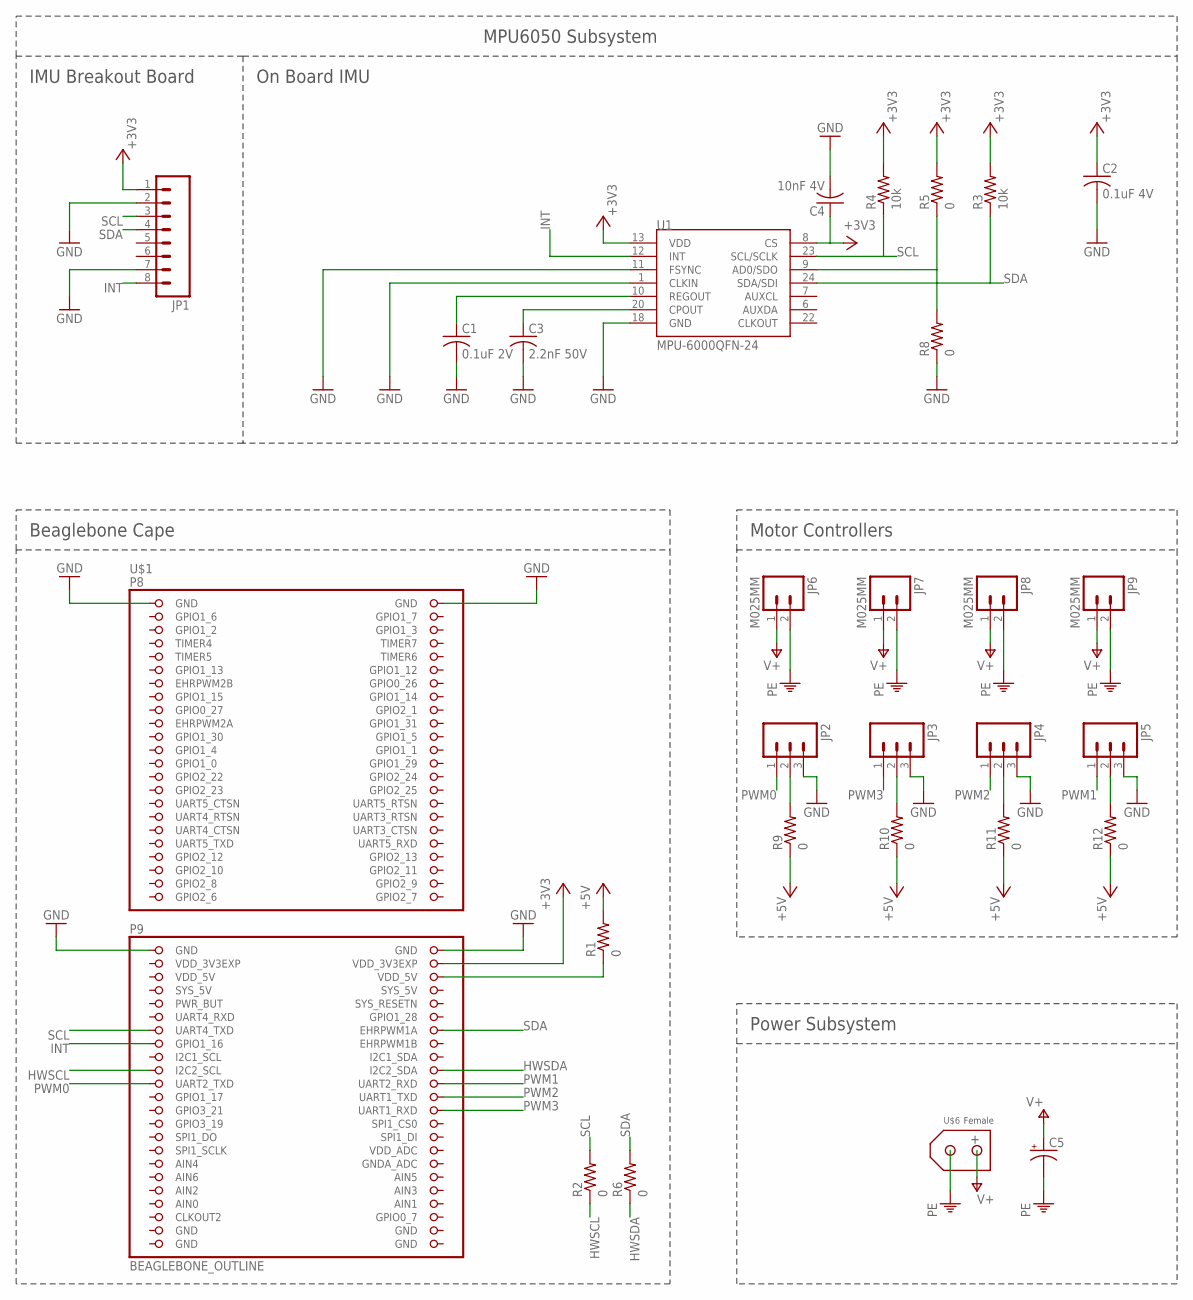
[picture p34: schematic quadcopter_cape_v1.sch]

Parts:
C1: 0.1uF 2V; C0603
C2: 0.1uF 4V; C0603
C3: 2.2nF 50V; C0603
C4: 10nF 4V; C0603
C5: 10UF-25V-20%(PTH); CPOL-RADIAL-10UF-25V
JP1: M081X08; 1X08
JP2, JP3, JP4, JP5: M03PTH; 1X03
JP6, JP7, JP8, JP9: M025MM; SCREWTERMINAL-5MM-2
R1, R2, R5, R6, R8, R9, R10, R11, R12: 0; R0603
R3, R4: 10k; R0603
U1: MPU-6000QFN-24; QFN-24-TESTING
U$1: BEAGLEBONE_OUTLINE; BEAGLEBONE_SHIELD
U$6: XT60

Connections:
+3V3: C2.1, C4.1, JP1.1, R3.2, R4.2, R5.2, U1.8 (CS), U1.13 (VDD), U$1.50 (VDD_3V3EXP)
+5V: R1.2, R9.1, R10.1, R11.1, R12.1
AIN0: U$1.85 (AIN0)
GND: C1.2, C2.2, C3.2, C4.2, JP1.2, JP1.7, JP2.3, JP3.3, JP4.3, JP5.3, R8.1, U1.1 (CLKIN), U1.11 (FSYNC), U1.18 (GND), U$1.1 (GND), U$1.2 (GND), U$1.47 (GND), U$1.48 (GND), U$1.89 (GND), U$1.90 (GND), U$1.91 (GND), U$1.92 (GND)
HWSCL: R2.1, U$1.65 (I2C2_SCL)
HWSDA: R6.1, U$1.66 (I2C2_SDA)
INT: JP1.8, U1.12 (INT), U$1.61 (GPIO1_16)
unnamed: R1.1, U$1.52 (VDD_5V)
unnamed: C1.1, U1.10 (REGOUT)
unnamed: C3.1, U1.20 (CPOUT)
unnamed: R5.1, R8.2, U1.9 (AD0/SDO)
unnamed: JP2.2, R9.2
unnamed: JP3.2, R10.2
unnamed: JP4.2, R11.2
unnamed: JP5.2, R12.2
PE: C5.2 (-), JP6.2, JP7.2, JP8.2, JP9.2, U$6.GND
PWM0: JP2.1, U$1.67 (UART2_TXD)
PWM1: JP5.1, U$1.68 (UART2_RXD)
PWM2: JP4.1, U$1.70 (UART1_TXD)
PWM3: JP3.1, U$1.72 (UART1_RXD)
SCL: JP1.3, R2.2, R4.1, U1.23 (SCL/SCLK), U$1.59 (UART4_TXD)
SDA: JP1.4, R3.1, R6.2, U1.24 (SDA/SDI), U$1.60 (EHRPWM1A)
SYS_5V: U$1.53 (SYS_5V)
V+: C5.1 (+), JP6.1, JP7.1, JP8.1, JP9.1, U$6.PWR
VDD_3V3EXP: U$1.49 (VDD_3V3EXP)
VDD_5V: U$1.51 (VDD_5V)

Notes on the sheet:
Beaglebone Cape
Motor Controllers
IMU Breakout Board
MPU6050 Subsystem
On Board IMU
Power Subsystem
Female

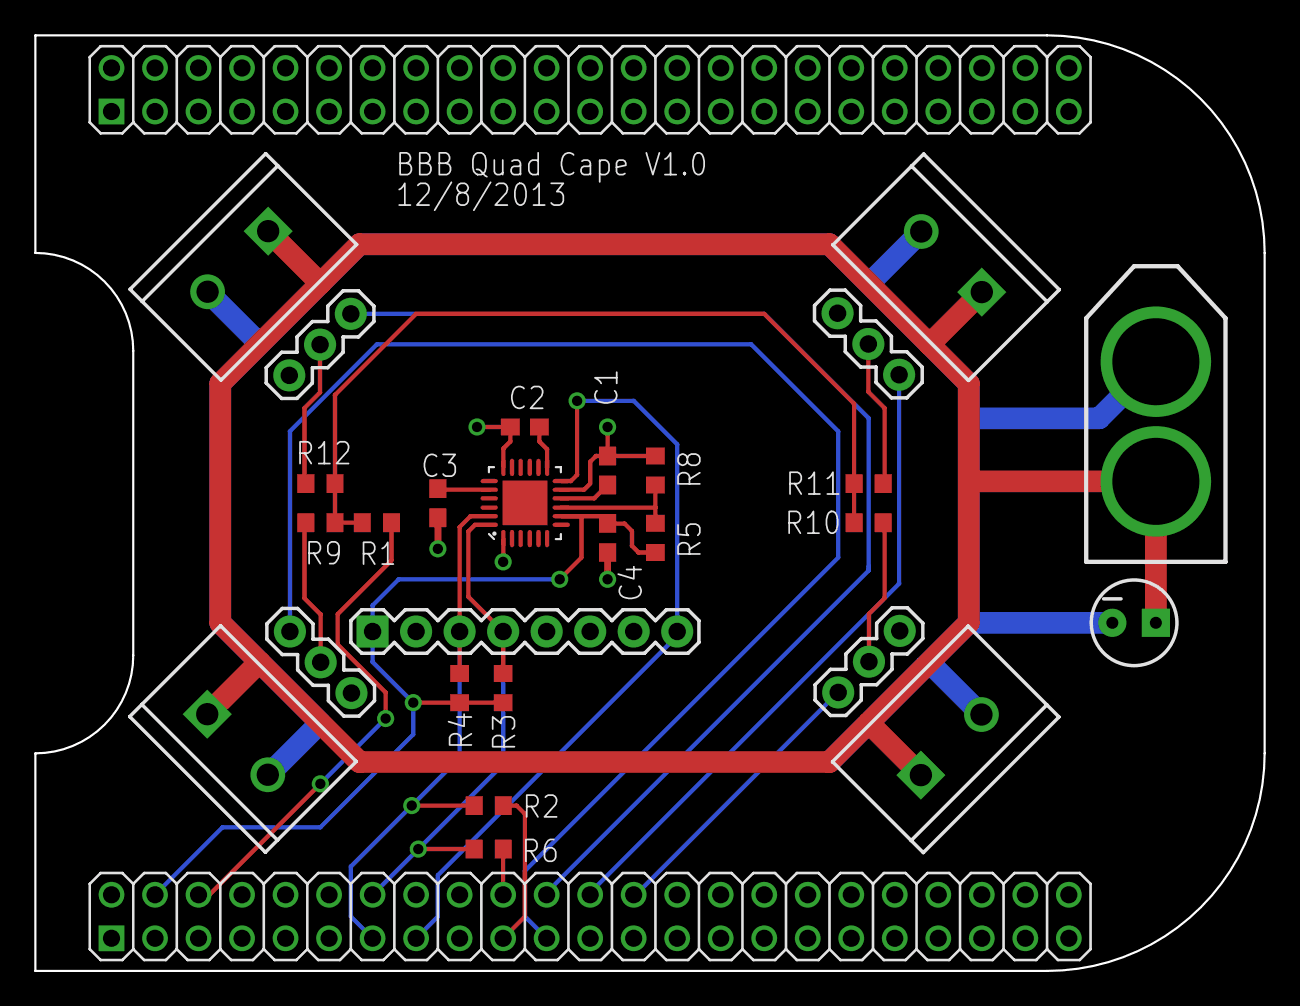
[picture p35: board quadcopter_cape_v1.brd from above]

Board: 2 copper layers, 71.8 x 54.6 mm, 28 parts (0 on the bottom side), 22 nets.

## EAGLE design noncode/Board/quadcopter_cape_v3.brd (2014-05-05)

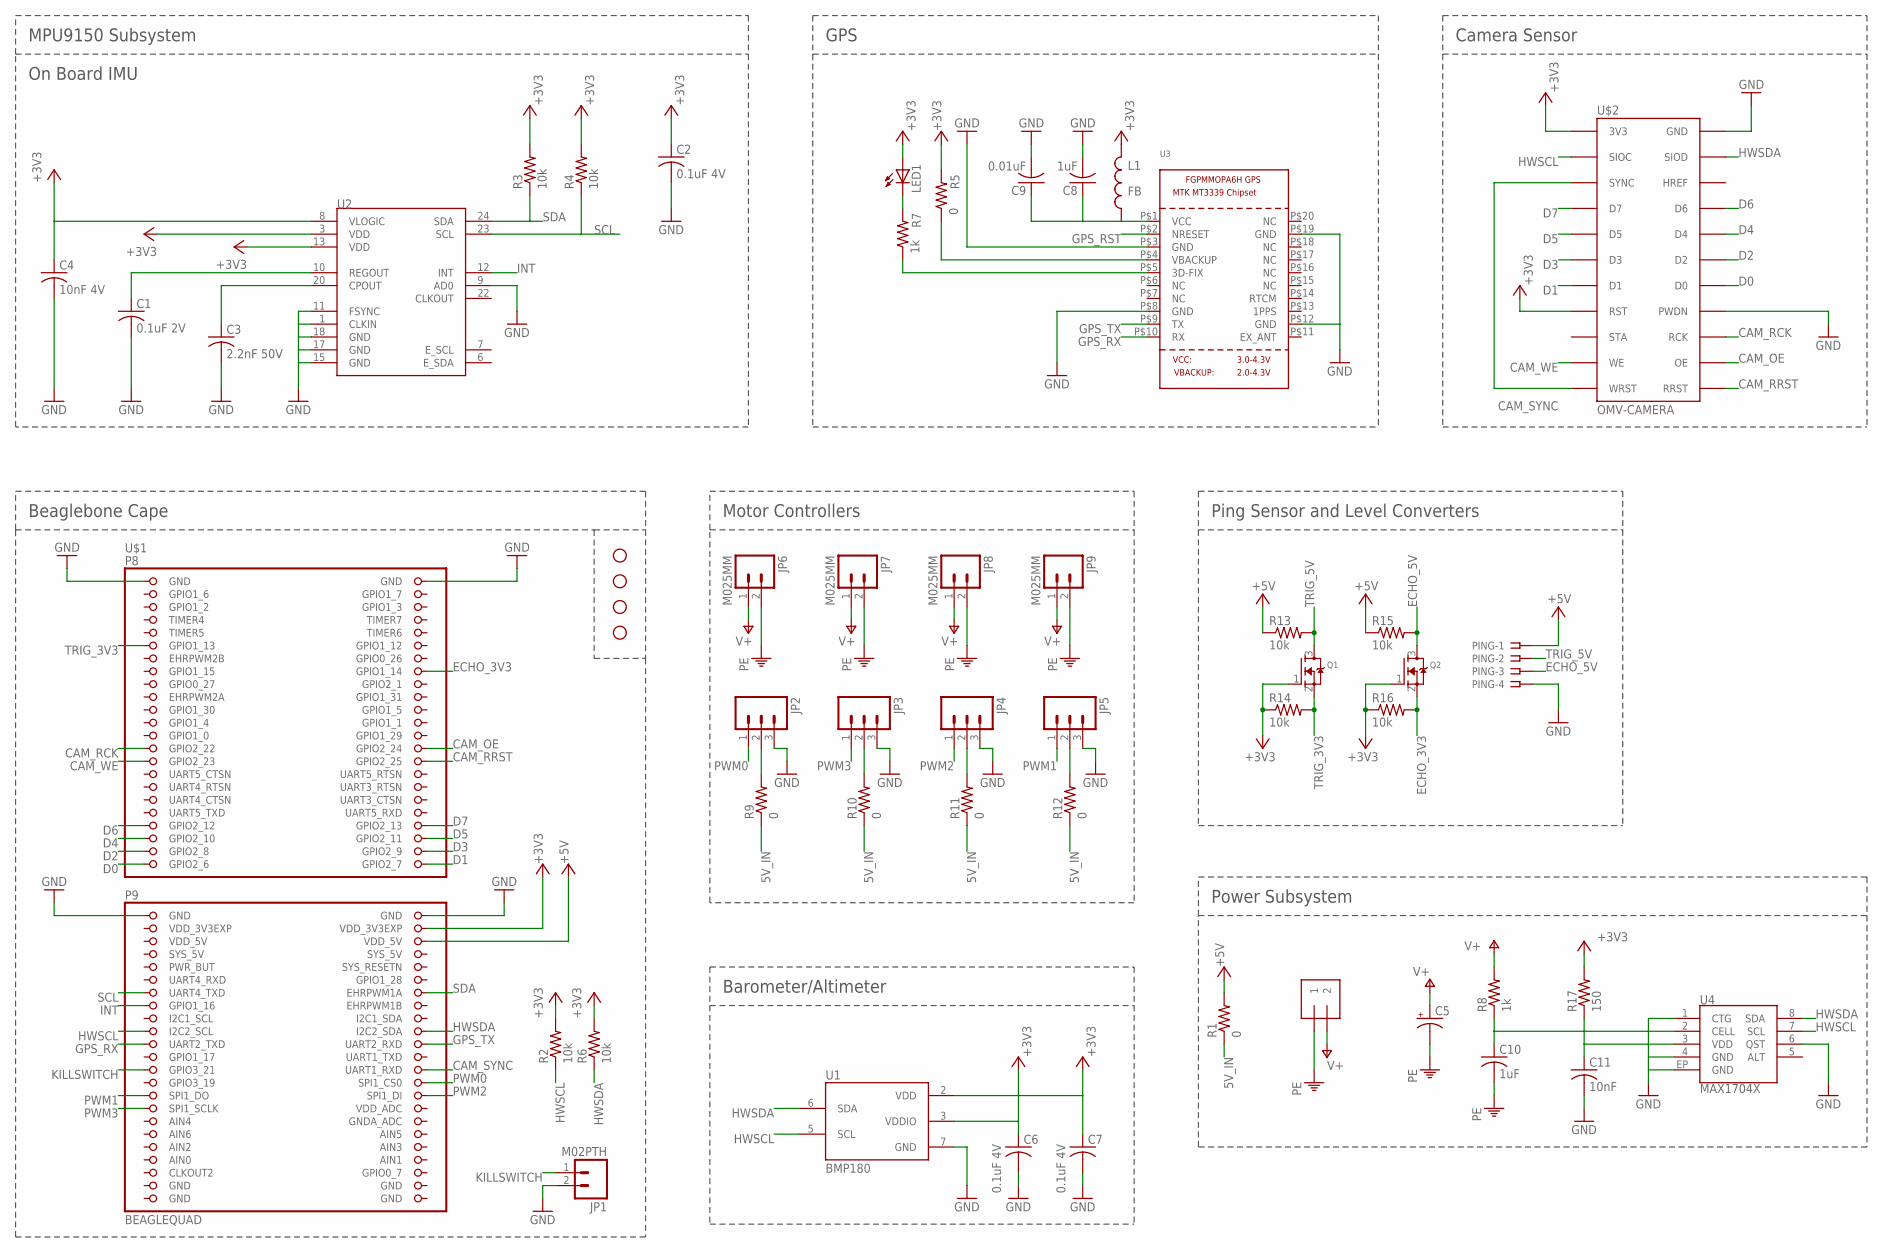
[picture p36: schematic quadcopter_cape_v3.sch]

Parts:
C1: 0.1uF 2V; C0805
C2, C6, C7: 0.1uF 4V; C0805
C3: 2.2nF 50V; C0805
C4: 10nF 4V; C0805
C5: 10UF-25V-20%(PTH); CPOL-RADIAL-10UF-25V
C8, C10: 1uF; C0805
C9: 0.01uF; C0805
C11: 10nF; C0805
JP1: M02PTH; 1X02
JP2, JP3, JP4, JP5: M03PTH; 1X03
JP6, JP7, JP8, JP9: M025MM; SCREWTERMINAL-5MM-2
L1: FB; 0805
LED1: LEDCHIP-LED0805; CHIP-LED0805
PING: SSW-104-02-S-S-RA
Q1, Q2: MOSFET-NREFLOW; SOT23
R1, R5, R9, R10, R11, R12: 0; M0805
R2, R3, R4, R6, R13, R14, R15, R16: 10k; M0805
R7, R8: 1k; M0805
R17: 150; M0805
STANDOFF1, STANDOFF2, STANDOFF3, STANDOFF4: STAND-OFF
U1: BMP180
U2: MPU-9150QFN-24-NP; QFN-24-NP
U3: GPS_FGPMMOPA6H; FGPMMOPA6H
U4: MAX1704X; TDFN-8
U$1: BEAGLEQUAD; BEAGLEQUAD_SHIELD
U$2: OMV-CAMERA
U$3: 1X2-12AWG

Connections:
5V_IN: R1.1, R9.1, R10.1, R11.1, R12.1
+3V3: C2.1, C4.1, C6.1, C7.1, L1.2, LED1.A, Q1.1 (G), Q2.1 (G), R2.2, R3.2, R4.2, R5.2, R6.2, R14.1, R16.1, R17.2, U1.2 (VDD), U1.3 (VDDIO), U2.3 (VDD), U2.8 (VLOGIC), U2.13 (VDD), U$1.50 (VDD_3V3EXP), U$2.3V3, U$2.RST
+5V: PING.1, R1.2, R13.1, R15.1, U$1.52 (VDD_5V)
AIN0: U$1.85 (AIN0)
CAM_OE: U$1.28 (GPIO2_24), U$2.OE
CAM_RCK: U$1.27 (GPIO2_22), U$2.RCK
CAM_RRST: U$1.30 (GPIO2_25), U$2.RRST
CAM_SYNC: U$1.72 (UART1_RXD), U$2.SYNC, U$2.WRST
CAM_WE: U$1.29 (GPIO2_23), U$2.WE
D0: U$1.45 (GPIO2_6), U$2.D0
D1: U$1.46 (GPIO2_7), U$2.D1
D2: U$1.43 (GPIO2_8), U$2.D2
D3: U$1.44 (GPIO2_9), U$2.D3
D4: U$1.41 (GPIO2_10), U$2.D4
D5: U$1.42 (GPIO2_11), U$2.D5
D6: U$1.39 (GPIO2_12), U$2.D6
D7: U$1.40 (GPIO2_13), U$2.D7
ECHO_3V3: Q2.2 (S), R16.2, U$1.16 (GPIO1_14)
ECHO_5V: PING.3, Q2.3 (D), R15.2
GND: C1.2, C2.2, C3.2, C4.2, C6.2, C7.2, C8.2, C9.2, C11.2, JP1.2, JP2.3, JP3.3, JP4.3, JP5.3, PING.4, U1.7 (GND), U2.1 (CLKIN), U2.9 (AD0), U2.11 (FSYNC), U2.15 (GND), U2.17 (GND), U2.18 (GND), U3.P$3 (GND), U3.P$8 (GND), U3.P$12 (GND), U3.P$19 (GND), U4.1 (CTG), U4.4 (GND), U4.6 (QST), U4.EP (GND), U$1.1 (GND), U$1.2 (GND), U$1.47 (GND), U$1.48 (GND), U$1.89 (GND), U$1.90 (GND), U$1.91 (GND), U$1.92 (GND), U$2.GND, U$2.PWDN
GPS_RST: U3.P$2 (NRESET)
GPS_RX: U3.P$10 (RX), U$1.67 (UART2_TXD)
GPS_TX: U3.P$9 (TX), U$1.68 (UART2_RXD)
HWSCL: R2.1, U1.5 (SCL), U4.7 (SCL), U$1.65 (I2C2_SCL), U$2.SIOC
HWSDA: R6.1, U1.6 (SDA), U4.8 (SDA), U$1.66 (I2C2_SDA), U$2.SIOD
INT: U2.12 (INT), U$1.61 (GPIO1_16)
KILLSWITCH: JP1.1, U$1.71 (GPIO3_21)
unnamed: C10.1, R8.1, U4.2 (CELL)
unnamed: C1.1, U2.10 (REGOUT)
unnamed: R5.1, U3.P$4 (VBACKUP)
unnamed: C3.1, U2.20 (CPOUT)
unnamed: R7.1, U3.P$5 (3D-FIX)
unnamed: LED1.C, R7.2
unnamed: C8.1, C9.1, L1.1, U3.P$1 (VCC)
unnamed: JP2.2, R9.2
unnamed: JP3.2, R10.2
unnamed: JP4.2, R11.2
unnamed: JP5.2, R12.2
unnamed: C11.1, R17.1, U4.3 (VDD)
PE: C5.2 (-), C10.2, JP6.2, JP7.2, JP8.2, JP9.2, U$3.P$1 (1)
PWM0: JP2.1, U$1.74 (SPI1_CS0)
PWM1: JP5.1, U$1.75 (SPI1_DO)
PWM2: JP4.1, U$1.76 (SPI1_DI)
PWM3: JP3.1, U$1.77 (SPI1_SCLK)
SCL: R4.1, U2.23 (SCL), U$1.59 (UART4_TXD)
SDA: R3.1, U2.24 (SDA), U$1.60 (EHRPWM1A)
SYS_5V: U$1.53 (SYS_5V)
TRIG_3V3: Q1.2 (S), R14.2, U$1.11 (GPIO1_13)
TRIG_5V: PING.2, Q1.3 (D), R13.2
V+: C5.1 (+), JP6.1, JP7.1, JP8.1, JP9.1, R8.2, U$3.P$2 (2)
VDD_3V3EXP: U$1.49 (VDD_3V3EXP)
VDD_5V: U$1.51 (VDD_5V)

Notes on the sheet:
Beaglebone Cape
Motor Controllers
MPU9150 Subsystem
On Board IMU
Power Subsystem
Ping Sensor and Level Converters
Camera Sensor
Barometer/Altimeter
GPS

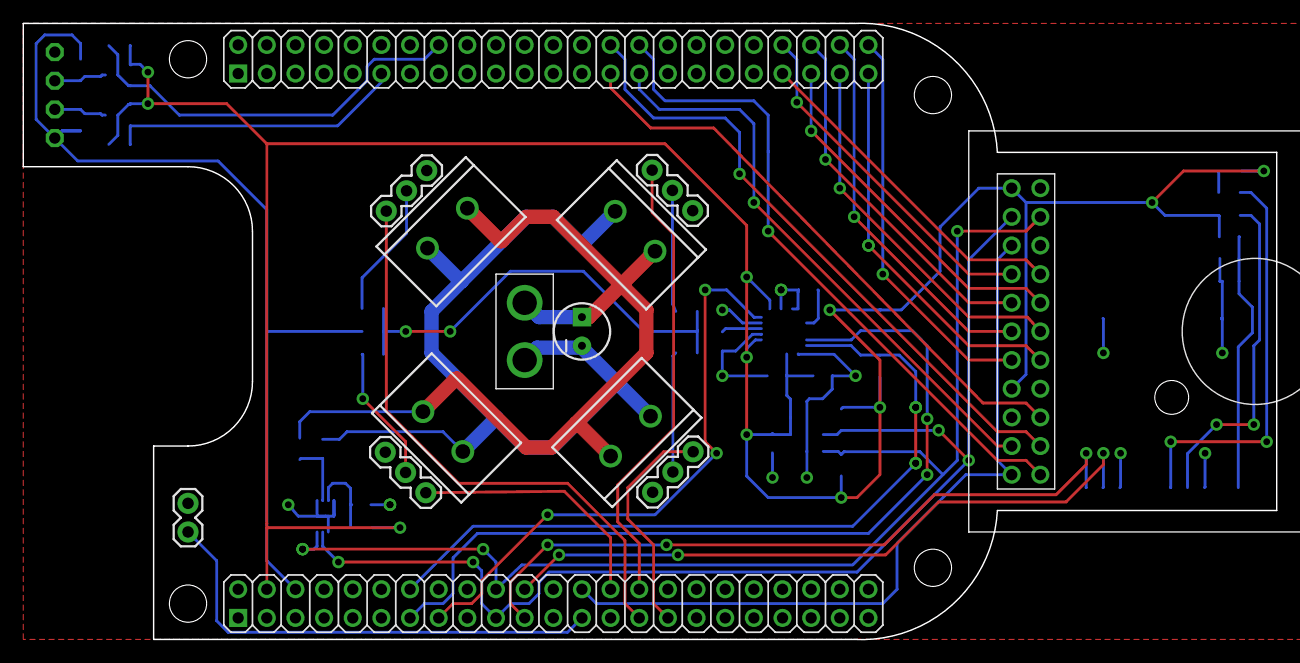
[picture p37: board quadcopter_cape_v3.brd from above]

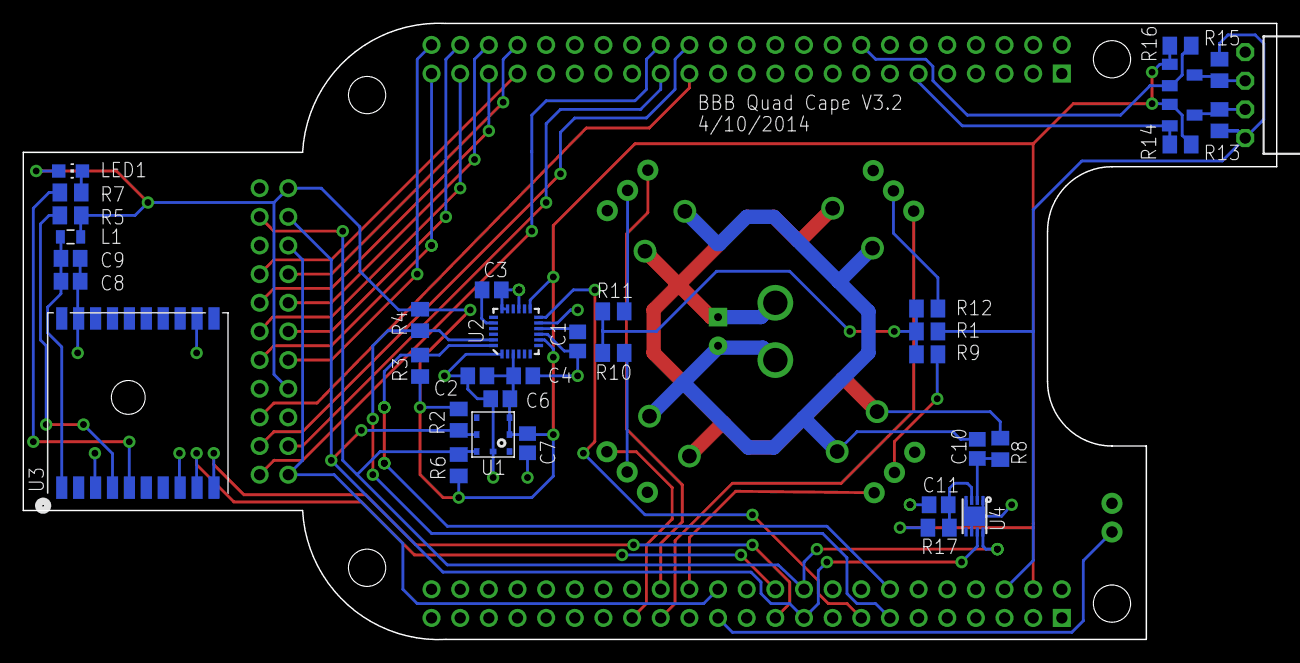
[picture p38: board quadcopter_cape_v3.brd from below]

Board: 2 copper layers, 111.1 x 54.6 mm, 53 parts (36 on the bottom side), 47 nets.

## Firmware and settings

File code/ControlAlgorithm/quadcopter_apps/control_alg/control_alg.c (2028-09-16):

#include <stdio.h>
#include <stdlib.h>
#include <prussdrv.h>
#include <pruss_intc_mapping.h>
#include <math.h>
#include <signal.h>
#include <fcntl.h>
#include <string.h>
#include <unistd.h>
#include <sys/mman.h>
#include <native/task.h>
#include <native/timer.h>

#include "control_alg.h"

RT_TASK demo_task;

volatile static void *pruDataMem;
volatile static signed int *pruDataMem_int;

void signal_handler(int sig){
	pruDataMem_int[0] = 0;
}

int get_set_point(set_point_t * goal, PID_t * PID_pitch, PID_t * PID_roll, PID_t * PID_yaw, comp_filter_t * theta_y){
	static int f = 0;
	static int num_since_last = 0;
	static int alive = 1;
	static int armed = 0;
	static double roll_goal = 0;
	static double pitch_goal = 0;
	static double yaw_goal = 0;
	static double z_goal = 0;
	static int zero_throttle_seen = 0;
	if (f == 0){
		f = open("/tmp/quadtempfs/BeagleQuad_ControlFifo.txt", O_NONBLOCK | O_RDONLY);
		if (f <=0 ){
			printf("couldn't open control file\n");
			pruDataMem_int[0] = 0;
		}
	}

	char buffer[256];
	int num_read = read(f, buffer, 256);
	buffer[num_read] = '\0';
	//message format:
	//throttle,aileron,elevator,rudder
	//throttle is negated
	//when increased:
	//aileron should roll right->set point increase
	//elevator should roll back->set point decrease
	//rudder should turn right->set point decrease
	int recieved_joy_update = 0;
	if (num_read>=1){
		num_since_last = 0;
		char * pch;
		pch = strtok(buffer, "\n");
		while(pch != NULL){
			//			printf("%s\n", pch);
			if (pch[0] == 'p' && pch[1] =='i' && pch[2] == 'd' && pch[3] == ':'){
				double rp, ri, rd, pp, pi, pd, yp, yi, yd;
				sscanf(pch, "pid: %lf %lf %lf %lf %lf %lf %lf %lf %lf", &pp, &pi, &pd, &rp, &ri, &rd, &yp, &yi, &yd);
				//printf("%lf %lf %lf %lf %lf %lf %lf %lf %lf\n", pp, pi, pd, rp, ri, rd, yp, yi, yd);

				PID_pitch->kP = pp;
				PID_pitch->kI = pi;
				PID_pitch->kD = pd;
				PID_roll->kP = rp;
				PID_roll->kI = ri;
				PID_roll->kD = rd;
				PID_yaw->kP = yp;
				PID_yaw->kI = yi;
				PID_yaw->kD = yd;

				//printf("updated pid: %d %d %d, %d %d %d, %d %d %d\n", rp, ri, rd, pp, pi, pd, yp, yi, yd);
			}else if (pch[0] == 'j' && pch[1] == 'o' && pch[2] == 'y' && pch[3] == ':'){
				recieved_joy_update = 1;

				sscanf(pch, "joy: %lf,%lf,%lf,%lf", &(z_goal), &(roll_goal), &(pitch_goal), &(yaw_goal));
				//printf("%f %f %f %f\n", z_goal, roll_goal, pitch_goal, yaw_goal);
				//printf("--\n");

				//pitch_goal += 5000;
				fflush(stdout);

				z_goal = (z_goal+32000)*.8;
				if (z_goal > 1000 && zero_throttle_seen){
					armed = 1;
				} else{
					armed = 0;
					zero_throttle_seen =1;
				}

				roll_goal/=-1500.0f;

				pitch_goal/=1500.0f;

				yaw_goal/=(11796*3); //turn 90 degrees per second
			}
			pch = strtok(NULL, "\n");
		}
		//goal->yaw = 0;
		//goal->pitch = 0;
		//goal->roll = 0;


		//printf("throttle: %f roll: %f pitch: %f yaw: %f\n", z_goal, roll_goal, pitch_goal, yaw_goal);
	}
	if (!recieved_joy_update){
		num_since_last+=1;
	}
	if (num_since_last >= 250){
		alive = 0;
	}
	if (!alive){
		pruDataMem_int[0] = 0;
		goal->yaw = 0;
		goal->pitch = 0;
		goal->yaw = 0;
		printf("controller timed out\n");
		exit(0);
	}
	
	if (fabs(yaw_goal) < .0001){ //arbitrary yaw rate
		goal->yaw = theta_y->th; //set the goal to the current theta if the user is not yawing.
	}

	goal->yaw += yaw_goal;
	goal->pitch = pitch_goal;
	goal->roll = roll_goal;
	goal->z = z_goal;


	usleep(0);
	return armed;


}

void init_PID(PID_t * PID_x, double kP, double kI, double kD){
	PID_x->kP = kP;
	PID_x->kI = kI;
	PID_x->I = 0;
	PID_x->kD = kD;
	PID_x->D = 0; 
}

void init_filter(comp_filter_t * comp_filter, double alpha, double beta, double g){
	comp_filter->alpha = alpha;
	comp_filter->beta = beta;
	comp_filter->g = g;
	comp_filter->th = 0;
}


void calculate_next_comp_filter(comp_filter_t * prev_data, double acc, double gyro, double dt){

	gyro = (gyro/GYRO_MAX_RAW)*GYRO_SENSITIVITY;
	double accel_angle = acc/prev_data->g;
	accel_angle = MAX(MIN(accel_angle, 1.0), -1.0);
	accel_angle = asin(accel_angle);
	prev_data->th = prev_data->alpha*(prev_data->th + gyro*dt) + prev_data->beta*accel_angle*RAD_TO_DEG;
}

void get_imu_frame(imu_data_t * imu_frame){
	rt_task_wait_period(NULL);
	//while(!pruDataMem_int[1] &&(pruDataMem_int[1000])){ // wait for pru to signal that new data is available
	//}


	imu_frame->x_a = (signed short)pruDataMem_int[2];
	imu_frame->y_a = (signed short)pruDataMem_int[3];
	imu_frame->z_a = (signed short)pruDataMem_int[4];
	imu_frame->x_g = (signed short)pruDataMem_int[5];
	imu_frame->y_g = (signed short)pruDataMem_int[6];
	imu_frame->z_g = (signed short)pruDataMem_int[7];
	imu_frame->sample_num = pruDataMem_int[12];

}

pru_pwm_frame_t * get_pwm_pointer(){
	pru_pwm_frame_t * pwm_frame = malloc(sizeof(pru_pwm_frame_t));
	pwm_frame->zero = &(pruDataMem_int[PWM_0_ADDRESS]);
	pwm_frame->one = &(pruDataMem_int[PWM_1_ADDRESS]);
	pwm_frame->two = &(pruDataMem_int[PWM_2_ADDRESS]);
	pwm_frame->three = &(pruDataMem_int[PWM_3_ADDRESS]);
	return pwm_frame;
}

void initialize_pru(){
	unsigned int ret;
	tpruss_intc_initdata pruss_intc_initdata = PRUSS_INTC_INITDATA;

	prussdrv_init ();
	/* Open PRU Interrupt */
	ret = prussdrv_open(PRU_EVTOUT_0);
	if (ret)
	{
		printf("prussdrv_open open failed\n");
		exit(ret);
	}

	/* Get the interrupt initialized */
	prussdrv_pruintc_init(&pruss_intc_initdata);

	//Initialize pointer to PRU data memory
	if (PRU_NUM == 0)
	{
		prussdrv_map_prumem (PRUSS0_PRU0_DATARAM, &pruDataMem);
	}
	else if (PRU_NUM == 1)
	{
		prussdrv_map_prumem (PRUSS0_PRU1_DATARAM, &pruDataMem);
	}  
	pruDataMem_int = (volatile signed int*) pruDataMem;
}
void start_pru(){
	pruDataMem_int[0] = 1;
	pruDataMem_int[13] = 0;
	prussdrv_exec_program (PRU_NUM, "./control_alg.bin");
}


void uninitialize_pru(){
	pruDataMem_int[0] = 0;
	pruDataMem_int[13] = 0;

	/* Wait until PRU0 has finished execution */
	printf("\tINFO: Waiting for HALT command.\r\n");
	prussdrv_pru_wait_event (PRU_EVTOUT_0);

	printf("\tINFO: PRU completed transfer.\r\n");
	prussdrv_pru_clear_event (PRU0_ARM_INTERRUPT);

	/* Disable PRU and close memory mapping*/
	prussdrv_pru_disable (PRU_NUM);
	prussdrv_exit ();


}

imu_data_t * get_calibration_data(){
	imu_data_t * calib_data = malloc(sizeof(imu_data_t));
	imu_data_t imu_data;
	calib_data->x_a = 0;
	calib_data->y_a = 0;
	calib_data->z_a = 0;
	calib_data->x_g = 0;
	calib_data->y_g = 0;
	calib_data->z_g = 0;

	int i;
	printf("clearing DLPF on imu..\n");
	for (i = 0; (i < 1000); i++){
		
		pruDataMem_int[13] = 0;
		get_imu_frame(&imu_data);
		pruDataMem_int[1] = 0;
	}

	for (i = 0; (i < CALIBRATION_SAMPLES); i++){
		
		pruDataMem_int[13] = 0;
		get_imu_frame(&imu_data);
		pruDataMem_int[1] = 0;

		calib_data->x_a += imu_data.x_a;
		calib_data->y_a += imu_data.y_a;
		calib_data->z_a += imu_data.z_a;

		calib_data->x_g += imu_data.x_g;
		calib_data->y_g += imu_data.y_g;
		calib_data->z_g += imu_data.z_g;
	}
	calib_data->x_a /= CALIBRATION_SAMPLES;
	calib_data->y_a /= CALIBRATION_SAMPLES;
	calib_data->z_a /= CALIBRATION_SAMPLES;
	calib_data->x_g /= CALIBRATION_SAMPLES;
	calib_data->y_g /= CALIBRATION_SAMPLES;
	calib_data->z_g /= CALIBRATION_SAMPLES;
	return calib_data;
}

void init_pwm(pwm_frame_t * pwm_frame){
	pwm_frame->zero = PWM_OFF;
	pwm_frame->one = PWM_OFF;
	pwm_frame->two = PWM_OFF;
	pwm_frame->three = PWM_OFF;
}

void output_pwm(pwm_frame_t * pwm_frame_next, pru_pwm_frame_t * pwm_out){
	*(pwm_out->zero) = pwm_frame_next->zero;
	*(pwm_out->one) = pwm_frame_next->one;
	*(pwm_out->two) = pwm_frame_next->two;
	*(pwm_out->three) = pwm_frame_next->three;
	pruDataMem_int[1] = 0;

}

void load_pid_values(PID_t * PID_pitch, PID_t * PID_roll, PID_t * PID_yaw, PID_t * PID_z){
	FILE * fp = fopen(PID_FILE, "r");
	if (fp == NULL){
		fprintf(stderr, "Couldn't open the %s :(\n", PID_FILE);
		exit(-1);
	}
	int pp, pi, pd, rp, ri, rd, yp, yi, yd, zp, zi, zd;
	int num_values = fscanf(fp, "%d, %d, %d\n%d, %d, %d\n%d, %d, %d\n%d, %d, %d", 
			&pp, &pi, &pd,
			&rp, &ri, &rd,
			&yp, &yi, &yd,
			&zp, &zi, &zd);
	if (num_values != 12 || num_values == EOF){
		perror("scanf");
		fprintf(stderr, "You are a failure.  Please reformat your %s file.\n", PID_FILE);
		exit(-1);
	}
	init_PID(PID_pitch, pp, pi, pd);
	init_PID(PID_roll, rp, ri, rd);
	init_PID(PID_yaw, yp, yi, yd);
	init_PID(PID_z, zp, zi, zd);
	fclose(fp);
}

void demo (void * arg)
{
        rt_task_set_periodic(NULL, TM_NOW, 5000000);
	


	comp_filter_t * theta_p = malloc(sizeof(comp_filter_t));
	comp_filter_t * theta_r = malloc(sizeof(comp_filter_t));
	comp_filter_t * theta_y = malloc(sizeof(comp_filter_t));
	pwm_frame_t * next_pwm = malloc(sizeof(comp_filter_t));
	double * z_pos = malloc(sizeof(double)); 
	double * z_vel = malloc(sizeof(double));
	PID_t * PID_pitch = malloc(sizeof(PID_t));
	PID_t * PID_roll = malloc(sizeof(PID_t));
	PID_t * PID_yaw = malloc(sizeof(PID_t));
	PID_t * PID_z = malloc(sizeof(PID_t));
	set_point_t * goal = malloc(sizeof(set_point_t));
	set_point_t * cf = malloc(sizeof(set_point_t));

	FILE * response_log = fopen("system_response.csv", "w");
	if (response_log == NULL){
		fprintf(stderr, "Couldn't open response.csv");
		exit(-1);
	}
	fprintf(response_log, "bias,pitch,cf_pitch,roll,cf_roll,yaw,cf_yaw,z,m0,m1,m2,m3\n");
	load_pid_values(PID_pitch, PID_roll, PID_yaw, PID_z);

	initialize_pru();
	pru_pwm_frame_t * pwm_out = get_pwm_pointer();
	init_pwm(next_pwm);
	output_pwm(next_pwm, pwm_out);
	start_pru();

	imu_data_t * calib_data;
	FILE * calib_file = fopen("./cal.txt", "r");
	if (calib_file == NULL){
		printf("generating new calibration data\n");
		calib_data = get_calibration_data();
		calib_file = fopen("./cal.txt", "w");
		if (calib_file == NULL){
			fprintf(stderr, "couldn't open cal.txt\n");
		} else{
			fprintf(calib_file, "%f,%f,%f,%f,%f,%f\n", calib_data->x_a, calib_data->y_a, calib_data->z_a, calib_data->x_g, calib_data->y_g, calib_data->z_g);
			fclose(calib_file);
		}

		uninitialize_pru();
		exit(-1);
	} else{
		calib_data = malloc(sizeof(imu_data_t));
		fscanf(calib_file, "%lf,%lf,%lf,%lf,%lf,%lf\n", &(calib_data->x_a), &(calib_data->y_a), &(calib_data->z_a), &(calib_data->x_g), &(calib_data->y_g), &(calib_data->z_g));
		//		printf("cal data: %f, %f, %f, %f, %f, %f\n", calib_data->x_a, calib_data->y_a, calib_data->z_a, calib_data->x_g, calib_data->y_g, calib_data->z_g);
		fclose(calib_file);
	}

//	signal(SIGINT, signal_handler);
	printf("check calibration data for sanity: %f, %f, %f, %f, %f, %f\n", calib_data->x_a, calib_data->y_a, calib_data->z_a, calib_data->x_g, calib_data->y_g, calib_data->z_g);

	*z_pos = 0;
	*z_vel = 0;

	imu_data_t * imu_frame = malloc(sizeof(imu_data_t));

	init_filter(theta_p, ALPHA, BETA, G);
	init_filter(theta_r, ALPHA, BETA, G);
	init_filter(theta_y, 1, 0, G);


	double bias = 0;
	int count = 0;
	int time = 0;
	goal->z = 0;
	goal->pitch = 0;
	goal->roll = 0;
	goal->yaw = 0;
	while(pruDataMem_int[0] != 0){
		pruDataMem_int[13] = 0;

		get_imu_frame(imu_frame); //called because this basically controls our timesteps
		count++;
		if (imu_frame->sample_num != count){
			if (imu_frame->sample_num-count+1){
				printf("Skipped %d frames\n", imu_frame->sample_num-count+1);
			}
			count = imu_frame->sample_num;
		}

		calibrate_imu_frame(imu_frame, calib_data);
		if ((count % 20) == 0){
			printf ("I'm still here!\n");

			/*
			printf("bias: % 03f", bias);
			printf(", pitch: % 03.5f, cf_pitch: % 03.5f", theta_p->th, cf->pitch);
			printf(", roll: % 03.5f, cf_roll: % 03.5f", theta_r->th, cf->roll);
			printf(", yaw: % 03.5f, cf->yaw: % 03.5f", theta_y->th, cf->yaw);
			printf(", m0: %d, m1: %d, m2: %d, m3: %d\n", next_pwm->zero, next_pwm->one, next_pwm->two, next_pwm->three);
			*/
			printf("I: %f D: %f pitch: %f\n", PID_roll->I, PID_roll->D, theta_r->th);
			//printf("goal: pitch: %f roll: %f yaw: %f z: %f\n", goal->pitch, goal->roll, goal->yaw, bias);
			//printf("goalyaw: %f\n", goal->yaw);

		}


		if (get_set_point(goal, PID_pitch, PID_roll, PID_yaw, theta_y)){
			bias = goal->z;
			if (bias < BIAS_MAX){
				//bias = BIAS_MAX/(1.0f+exp(-0.01656695d*time+6.2126d));
			} else{
				//bias = BIAS_MAX;
				bias = BIAS_MAX;
			}

			filter_loop(imu_frame, theta_p, theta_r, theta_y, z_pos, z_vel);
			calculate_next_pwm(next_pwm, theta_p, theta_r, theta_y, z_pos, z_vel, PID_pitch, PID_roll, PID_yaw, PID_z, goal, bias, cf, imu_frame);
			output_pwm(next_pwm, pwm_out);


			//fprintf(response_log, "%f,%3.5f,%3.5f,%3.5f,%3.5f,%3.5f,%3.5f,%3.5f,\t%d,%d,%d,%d\n", bias, theta_p->th,cf->pitch, theta_r->th,cf->roll, theta_y->th, cf->yaw, *z_vel, next_pwm->zero, next_pwm->one, next_pwm->two, next_pwm->three);
			//		printf("x_g: % 05.5f, x_a: % 05.5f, y_g: % 05.5f, y_a: % 05.5f, z_g: % 05.5f, z_a: % 05.5f\n", imu_frame->x_g, imu_frame->x_a, imu_frame->y_g, imu_frame->y_a, imu_frame->z_g, imu_frame->z_a);
			time += 1;
		} else{ // not armed
			time = 0;
			init_pwm(next_pwm);
			output_pwm(next_pwm, pwm_out);
			PID_pitch->I = 0;
			PID_pitch->D = 0;
			PID_roll->I = 0;
			PID_roll->D = 0;
			PID_yaw->I = 0;
			PID_yaw->D = 0;
			PID_z->I = 0;
			PID_z->D = 0;
			goal->z = 0;
			goal->roll = 0;
			goal->yaw = 0;
			goal->pitch = 0;
			theta_y->th = 0;
		}
		
	}
	printf("exiting...\n");

	uninitialize_pru();
	fclose(response_log);
	free(theta_p);
	free(theta_r);
	free(theta_y);
	free(z_pos);
	free(z_vel);
	free(calib_data);
	free(PID_pitch);
	free(PID_roll);
	free(PID_yaw);
	free(PID_z);
	free(goal);
	free(pwm_out);
	free(next_pwm);	
	free(cf);
	free(imu_frame);
	//return(0);
}


int main(int argc, char* argv[])
{
        signal(SIGTERM, signal_handler);
        signal(SIGINT, signal_handler);

        /* Avoids memory swapping for this program */
        mlockall(MCL_CURRENT|MCL_FUTURE);

        /*
         * Arguments: &task,
         *            name,
         *            stack size (0=default),
         *            priority,
         *            mode (FPU, start suspended, ...)
         */
        rt_task_create(&demo_task, "trivial", 0, 99, 0);

        /*
         * Arguments: &task,
         *            task function,
         *            function argument
         */
        rt_task_start(&demo_task, &demo, NULL);

        pause();

        rt_task_delete(&demo_task);
}


void calibrate_imu_frame(imu_data_t * imu_frame, imu_data_t * calib_data){
	imu_frame->x_a -= calib_data->x_a;
	imu_frame->y_a -= calib_data->y_a;
	imu_frame->z_a -= calib_data->z_a + 1;

	imu_frame->x_g -= calib_data->x_g;
	imu_frame->y_g -= calib_data->y_g;
	imu_frame->z_g -= calib_data->z_g;
}

void filter_loop(imu_data_t * imu_frame, comp_filter_t * theta_p, comp_filter_t * theta_r, comp_filter_t * theta_y, double * z_pos, double * z_vel){
	double temp_z_acc = imu_frame->z_a*fabs(cos(theta_p->th/RAD_TO_DEG)*cos(theta_r->th/RAD_TO_DEG));
	temp_z_acc = ((temp_z_acc/32768.0f)*8.0f);
	*z_vel += temp_z_acc;

	//forward is +y is towards the ethernet port
	//right is +x is header P9
	//up is +z is the vector pointing from the cape to the beaglebone
	calculate_next_comp_filter(theta_p, -imu_frame->y_a, imu_frame->x_g, DT);
	calculate_next_comp_filter(theta_r, imu_frame->x_a, imu_frame->y_g, DT);
	calculate_next_comp_filter(theta_y, -imu_frame->z_a, -imu_frame->z_g, DT);
}

void calculate_next_pwm(pwm_frame_t * next_pwm, comp_filter_t * theta_p, comp_filter_t * theta_r, comp_filter_t * theta_y, double * z_pos, double * z_vel, PID_t * PID_pitch, PID_t * PID_roll, PID_t * PID_yaw, PID_t * PID_z, set_point_t * goal, int bias, set_point_t * cf, imu_data_t * imu_data){
	double d_pitch = PID_loop(goal->pitch, PID_pitch, theta_p->th);
	double d_roll = PID_loop(goal->roll, PID_roll, theta_r->th);
	double d_yaw = PID_loop(goal->yaw, PID_yaw, theta_y->th);
	double d_z = PID_loop(goal->z, PID_z, *z_vel);
	cf->roll = d_roll;
	cf->pitch = d_pitch;
	cf->yaw = d_yaw;

	d_z = 0;//FIXME
	//
	//d_yaw = 0;
	//d_roll = 0;
	//d_pitch = 0;

	next_pwm->zero = d_pitch + d_roll + d_yaw - d_z + PWM_MIN;
	next_pwm->one = -d_pitch + d_roll - d_yaw - d_z + PWM_MIN;
	next_pwm->two = -d_pitch - d_roll + d_yaw - d_z + PWM_MIN;
	next_pwm->three = d_pitch - d_roll - d_yaw - d_z + PWM_MIN;

	next_pwm->zero = next_pwm->zero * MULT0 + bias + BIAS0;
	next_pwm->one = next_pwm->one * MULT1 + bias + BIAS1;
	next_pwm->two = next_pwm->two * MULT2 + bias + BIAS2;
	next_pwm->three = next_pwm->three * MULT3 + bias + BIAS3;

	next_pwm->zero = MIN(PWM_MAX, MAX(PWM_MIN,next_pwm->zero));
	next_pwm->one = MIN(PWM_MAX, MAX(PWM_MIN,next_pwm->one));
	next_pwm->two = MIN(PWM_MAX, MAX(PWM_MIN,next_pwm->two));
	next_pwm->three = MIN(PWM_MAX, MAX(PWM_MIN,next_pwm->three));
}

double PID_loop(double goal, PID_t * PID_x, double value){
	double P, I, D, delta_error;
	delta_error = goal - value;

	P = delta_error;
	I = (PID_x->I + PID_x->kI*delta_error*DT);
	I = MIN(MAX_I, MAX(MIN_I,I));
	//PID_x->I = I*.998;
	PID_x->I = I;
	D = PID_x->D - value;
	PID_x->D = value;

	return P*PID_x->kP + I + D*PID_x->kD/DT;
}

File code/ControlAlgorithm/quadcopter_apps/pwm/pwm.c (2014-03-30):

#include <stdio.h>
#include <stdlib.h>
#include <prussdrv.h>
#include <pruss_intc_mapping.h>
#include <math.h>
#include <signal.h>
#define PRU_NUM 	0
#define PWM_0_ADDRESS 11
#define PWM_1_ADDRESS 8
#define PWM_2_ADDRESS 10
#define PWM_3_ADDRESS 9
#define ALPHA		.999
#define BETA		(1-ALPHA)
#define G		2048
#define AM33XX
#define CALIBRATION_SAMPLES 256
#define PI 3.141592653589793238462643383279502884197169399375105
#define RAD_TO_DEG	57.2957795f
#define DT		0.005f
#define PWM_MIN		105000
#define PWM_MAX		170000
#define MIN(a,b)	(a<b ? a : b)
#define MAX(a,b)	(a>b ? a : b)

#define GYRO_SENSITIVITY 2000 //gyro sensitivity in degrees/second
#define GYRO_MAX_RAW	32768 //maximum raw output of gyro

#define P_DEF		1000
#define I_DEF		.1
#define D_DEF		.1
#define TIME_STEP	0.002f


volatile static void *pruDataMem;
volatile static signed int *pruDataMem_int;



typedef struct pru_pwm_frame_t{
	volatile int* zero;
	volatile int* one;
	volatile int* two;
	volatile int* three;
} pru_pwm_frame_t;

typedef struct pwm_frame_t{
	int zero;
	int one;
	int two;
	int three;
} pwm_frame_t;
pru_pwm_frame_t * get_pwm_pointer();
void initialize_pru();
void start_pru();
void uninitialize_pru();
void signal_handler(int sig);

void signal_handler(int sig){
	pruDataMem_int[0] = 0;
}

pru_pwm_frame_t * get_pwm_pointer(){
	pru_pwm_frame_t * pwm_frame = malloc(sizeof(pru_pwm_frame_t));
	pwm_frame->zero = &(pruDataMem_int[PWM_0_ADDRESS]);
	pwm_frame->one = &(pruDataMem_int[PWM_1_ADDRESS]);
	pwm_frame->two = &(pruDataMem_int[PWM_2_ADDRESS]);
	pwm_frame->three = &(pruDataMem_int[PWM_3_ADDRESS]);
	return pwm_frame;
}

void initialize_pru(){
    unsigned int ret;
    tpruss_intc_initdata pruss_intc_initdata = PRUSS_INTC_INITDATA;

    prussdrv_init ();
    /* Open PRU Interrupt */
    ret = prussdrv_open(PRU_EVTOUT_0);
    if (ret)
    {
        printf("prussdrv_open open failed\n");
        exit(ret);
    }
    
    /* Get the interrupt initialized */
    prussdrv_pruintc_init(&pruss_intc_initdata);

    //Initialize pointer to PRU data memory
    if (PRU_NUM == 0)
    {
      prussdrv_map_prumem (PRUSS0_PRU0_DATARAM, &pruDataMem);
    }
    else if (PRU_NUM == 1)
    {
      prussdrv_map_prumem (PRUSS0_PRU1_DATARAM, &pruDataMem);
    }  
    pruDataMem_int = (volatile signed int*) pruDataMem;
}
void start_pru(){
    pruDataMem_int[0] = 1;
    prussdrv_exec_program (PRU_NUM, "./pwm_control_alg.bin");
}


void uninitialize_pru(){
    pruDataMem_int[0] = 0;

    /* Wait until PRU0 has finished execution */
    printf("\tINFO: Waiting for HALT command.\r\n");
    prussdrv_pru_wait_event (PRU_EVTOUT_0);

    printf("\tINFO: PRU completed transfer.\r\n");
    prussdrv_pru_clear_event (PRU0_ARM_INTERRUPT);

    /* Disable PRU and close memory mapping*/
    prussdrv_pru_disable (PRU_NUM);
    prussdrv_exit ();


}
void init_pwm(pwm_frame_t * pwm_frame){
	pwm_frame->zero = PWM_MIN;
	pwm_frame->one = PWM_MIN;
	pwm_frame->two = PWM_MIN;
	pwm_frame->three = PWM_MIN;
}

void output_pwm(pwm_frame_t * pwm_frame_next, pru_pwm_frame_t * pwm_out){
	*(pwm_out->zero) = pwm_frame_next->zero;
	*(pwm_out->one) = pwm_frame_next->one;
	*(pwm_out->two) = pwm_frame_next->two;
	*(pwm_out->three) = pwm_frame_next->three;
}

int main (void)
{

	pwm_frame_t * next_pwm = malloc(sizeof(pwm_frame_t));
	initialize_pru();
	start_pru();
	pru_pwm_frame_t * pwm_out = get_pwm_pointer();
	init_pwm(next_pwm);
	output_pwm(next_pwm, pwm_out);
        signal(SIGINT, signal_handler);

	while(pruDataMem_int[0] != 0){

		scanf("%d %d %d %d", &(next_pwm->zero), &(next_pwm->one), &(next_pwm->two), &(next_pwm->three));
		pruDataMem_int[2] = 0;
		next_pwm->zero *= 1000;
		next_pwm->one *= 1000;
		next_pwm->two *= 1000;
		next_pwm->three *= 1000;
		output_pwm(next_pwm, pwm_out);


	}

	uninitialize_pru();
	
	return(0);
}

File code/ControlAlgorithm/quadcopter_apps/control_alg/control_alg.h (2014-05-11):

#define PRU_NUM 	0
#define PWM_0_ADDRESS 11
#define PWM_1_ADDRESS 8
#define PWM_2_ADDRESS 10
#define PWM_3_ADDRESS 9
#define ALPHA		.99
#define BETA		(1-ALPHA)
//#define G		16384
#define G		2048
#define AM33XX
#define CALIBRATION_SAMPLES 256
#define PI 3.141592653589793238462643383279502884197169399375105
#define RAD_TO_DEG	57.2957795f
#define DT		.005f
#define PWM_OFF		115000
#define PWM_MIN		115000
#define PWM_MAX		170000
#define MIN(a,b)	(a<b ? a : b)
#define MAX(a,b)	(a>b ? a : b)
#define BIAS_INCREASE_RATE 1
//#define GYRO_SENSITIVITY 250
#define GYRO_SENSITIVITY 2000 //gyro sensitivity in degrees/second
#define GYRO_MAX_RAW	32768 //maximum raw output of gyro
#define MAX_I		2000
#define MIN_I		-MAX_I

#define BIAS0 0.0f// 10000.0f
#define BIAS1 0.0f//10000.0f
#define BIAS2 0.0f//10000.0f
#define BIAS3 0.0f//10000.0f

#define MULT0 1.00f
#define MULT1 1.00f
#define MULT2 1.00f
#define MULT3 1.00f

#define BIAS_MAX 50000
#define PID_FILE "../control_alg/pid_values.txt"
typedef struct imu_data_t{
	double x_a;
	double y_a;
	double z_a;
	double x_g;
	double y_g;
	double z_g;
	int sample_num;
	
}imu_data_t;

typedef struct comp_filter_t {
	double alpha;
	double th;
	double beta;
	double g;
} comp_filter_t;


typedef struct pru_pwm_frame_t{
	volatile int* zero;
	volatile int* one;
	volatile int* two;
	volatile int* three;
} pru_pwm_frame_t;

typedef struct pwm_frame_t{
	int zero;
	int one;
	int two;
	int three;
} pwm_frame_t;

typedef struct PID_t{
	double kP;
	double kI;
	double kD;
	double I;
	double D;
} PID_t;

typedef struct set_point_t{
	double pitch;
	double roll;
	double yaw;
	double z;
} set_point_t;

void calibrate_imu_frame(imu_data_t * imu_frame, imu_data_t * calib_data);
void filter_loop(imu_data_t * imu_frame, comp_filter_t * theta_p, comp_filter_t * theta_r, comp_filter_t * theta_y, double * z_pos, double * z_vel);
void init_filter(comp_filter_t * comp_filter, double alpha, double beta, double g);
void calculate_next_comp_filter(comp_filter_t * prev_data, double acc, double gyro, double dt);
void get_imu_frame(imu_data_t * imu_frame);
pru_pwm_frame_t * get_pwm_pointer();
void initialize_pru();
void start_pru();
void uninitialize_pru();
imu_data_t * get_calibration_data();
void calculate_next_pwm(pwm_frame_t * next_pwm, comp_filter_t * theta_p, comp_filter_t * theta_r, comp_filter_t * theta_y, double * z_pos, double * z_vel, PID_t * PID_pitch, PID_t * PID_roll, PID_t * PID_yaw, PID_t * PID_z, set_point_t * goal, int bias, set_point_t * cf, imu_data_t * imu_data);
void init_PID(PID_t * PID_x, double kP, double kI, double kD);
int get_set_point(set_point_t * goal, PID_t * PID_pitch, PID_t * PID_roll, PID_t * PID_yaw, comp_filter_t * theta_y);
double PID_loop(double goal, PID_t * PID_x, double value);
void signal_handler(int sig);
void load_pid_values(PID_t * PID_pitch, PID_t * PID_roll, PID_t * PID_yaw, PID_t * PID_z);

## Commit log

2000-01-01 Committing current beagle status
2000-01-01 commiting pwm stuff before branching to 2-wire imu
2000-01-01 added comments for what header pin each control line is connected to in the pru i2c bitbanging code
2000-01-01 now the address argument to the i2c functions is the actual address, not it shifted left.
2000-01-01 Trying to add last two channels to pwm
2000-01-01 got camera working, the endianess was backwards
2000-01-01 commented out ping code, made it quicker to change between rev1 and rev 2 in pwm code, added back safties
2000-01-01 simple complementary filter working
2000-01-01 resets PID loops and kills motors if throttle is off
    [control_alg.c, control_alg.h]
2000-01-01 got the control algorithm calibration function working
2000-01-01 got pwm working
2000-01-01 PID pitch and roll have fast response times with little overshoot and oscillations
    [control_alg.c, control_alg.h]
2000-01-01 refactored to separate constants, structs, and function prototypes; also, this is a pretty good version of the demo as it is stable, generally around the right angle
2000-01-01 Single time calibration for IMU (file) and pin resolution
2000-01-01 made a simple interface for ARM side programs to talk to the PRU
2000-01-01 imu data might be a little broken
    [control_alg.c]
2013-10-18 arduino i2c bit bang
2013-10-21 Adding pru stuff, the i2c example is in the example_apps/PRU_memQAccessPRUDataRam folder
2013-10-22 PRU I2C is working
2013-10-22 cleanup of the pru i2c
2013-10-23 adding base device tree. It disables the heartbeat LED, and more importantly, enables the PRU hardware. Back up the original in /boot, and copy this one there.
2013-11-02 trying changing the pwm loop to see if that's the problem
2013-11-03 really just committing the pwm stuff and the blink example
2013-11-06 two wire is almost working, committing as a milestone type thing
2013-11-06 2 channel pwm is working, still a timing issue to work out before moving on to 3 and 4 channels
    [pwm.c]
2013-11-06 two wire imu working
2013-11-10 IMU TWO WIRE IS WORKING
2013-11-10 changed the sample rate, uncommeted some other stuff
2013-11-13 Fixed saftey issue where pwm would go to half throttle at start. removed unecessary imu.c code, made imu.c print to stdout and out.csv, changed imu gpio ports for proof that it's easy reconfigured in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
    [pwm.c]
2013-12-04 modified imu.p to have a get_data function
2013-12-10 Added a test button to demonstrate socket.io callbacks (how neat was that?)
2013-12-14 Updated some initializations for motor control
2013-12-16 Added key bindings for LRUD and WASD for quadcopter control. Possibly didn't actually commit the changes in the control algorithm I claimed to commit earlier.
    [control_alg.c]
2013-12-16 fixed some gyro problems. Pitch still isn't working right for whatever reason.
    [control_alg.c]
2013-12-18 fixed axis system thing
    [control_alg.c]
2013-12-18 working on pwm
2013-12-18 committing pwm before making a new attempt at it
2013-12-18 adding more files for new pwm
2013-12-18 got pwm working again
2013-12-18 merged working pwm into control_alg
2013-12-20 committing before break. Start of control algorithm, pwm is working.
2014-01-22 camera code
2014-01-25 added kill switch
2014-01-26 updated setup script to build device tree overlay, load the overlay, and start the camera clock.
2014-01-29 added pin allocations for next board rev
    [quad pin allocations.csv]
2014-02-02 documented some of the constraints
    [quad pin allocations.csv]
2014-02-02 Changed gyro and accelerometer sensitivity settings to +/- 2g and +/- 250 deg/s.
2014-02-05 added saftey to pwm, cleaned up pwm, fixed memory bugs in control_alg
    [control_alg.c, control_alg.h, pwm.c]
2014-02-17 changed pid, fixed makefile
2014-03-16 ping sensor working
2014-03-16 working ultrasound and pwm
2014-03-26 moving to rev2 hopefully for good. pwm is borken in this rev
2014-03-29 fixed pru direct io and return address register issue in pru
    [control_alg.c, control_alg.h, ultrasound.c]
2014-03-29 pid working properly yay
2014-04-02 updated pin allocations
    [quad pin allocations.csv]
2014-04-02 updated pins
    [quad pin allocations.csv]
2014-04-05 this code is technically capable of flight, albeit very unstable flight.
    [control_alg.c, control_alg.h]
2014-04-07 made python script for calibrating pid values
2014-04-07 added more features to the calibrate code
2014-04-07 updated ultrasound pins
    [quad pin allocations.csv]
2014-04-07 added pid stuff
2014-04-07 added new safety so if the program crashes the pru will quit within a second
    [control_alg.c, control_alg.h]
2014-04-08 Added CAD files
    [BEAGLEBONE_BLACK_BOARD.SLDPRT, Landing Asm.SLDASM, Leg1 2.0 solid plywood.dxf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]
2014-04-08 fixed a ui yaw problem, added a safety where it won't throttle up unless it sees a zero throttle first.
    [control_alg.c, control_alg.h]
2014-04-08 Organized CAD files
    [Arm 1.0.DXF, Arm 1.0.SLDPRT, Arm 2.0.DXF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]
2014-04-10 Update README.md
    Added current branch note.
2014-04-11 Adding parts for an assembled quadcopter
    [ESC.SLDPRT, Lock Washer #4.SLDPRT, Motor.SLDPRT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]
2014-04-11 Added tabs to parts to keep them on one sheet
    [Arm 4.0 tabbed.dxf, Battery Tray 4.0 plywood tabbed.dxf, Frame 4.0 tabbed.dxf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]
2014-04-23 camera now saves bmps, changed shebang line for server, moved pid_values.txt, cleanup
2014-05-05 Added V1-3.2 schematics and board layout files, as well as the most up to date bill of materials
    [QuadBOM.xlsx, quadcopter_cape_v1.brd, quadcopter_cape_v1.sch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]
2014-05-11 Adding pictures of the board
2014-05-11 Added 3.2 board
2014-05-11 Adding PID pictures
2014-05-16 create tmpfs in setup_pru.sh, change camera program
2019-01-20 fixed unhandled merge conflict
    [quad pin allocations.csv]
2028-09-16 fixed frame rate

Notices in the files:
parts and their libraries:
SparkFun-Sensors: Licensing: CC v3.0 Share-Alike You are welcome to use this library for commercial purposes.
